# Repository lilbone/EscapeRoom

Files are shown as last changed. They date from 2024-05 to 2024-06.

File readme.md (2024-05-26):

# EscapeRoom Readme

## Beschreibung

Dieses Projekt besteht aus einem Escape Room, der auf einer Website dargestellt wird und von einem Raspberry Pi gehostet wird. Der Raspberry Pi fungiert als Webserver mit Apache 2 und betreibt zusätzlich einen MQTT-Server. Ein ESP8266 steuert mehrere Sensoren und Aktoren, darunter LEDs, Taster, einen LDR-Sensor, ein RFID-Chip Lesegerät und einen DHT-22 Sensor.

Die Website simuliert ein Haus mit drei Räumen und einem Flur. Die Spieler müssen verschiedene Rätsel lösen, die durch die Sensoren und Aktoren gesteuert werden, um von einem Raum zum nächsten zu gelangen. Die Kommunikation zwischen den Sensoren/Aktoren und der Website erfolgt über das MQTT-Protokoll.

## Funktionalitäten

*Raum 1:
   *Ein Spiegel, der beschlägt, wenn der DHT-22-Sensor angehaucht wird, um ein Passwort anzuzeigen. Mit diesem Passwort kann man den zweiten Raum öffnen.
*Raum 2:
   *Ein Morsecode-Rätsel, das durch eine leuchtende LED und einen Ton auf der Website angezeigt wird. Der entschlüsselte Code ermöglicht den Zugang zum nächsten Raum.
*Raum 3:
   *Es gibt drei Plattformen, die in der richtigen Reihenfolge betätigt werden müssen, um die Tür zu öffnen.
   *Vor dem 3. Raum muss man am ESP8266 den dritten Taster betätigen, um das Licht einzuschalten.
   *Ein Schrank enthält einen RFID-Chip, der sichtbar wird, wenn der LDR-Sensor beleuchtet wird.
   *Die letzte Tür kann nur mit dem RFID-Chip geöffnet werden, indem man ihn am ESP8266 einliest und danach die Tür öffnet.

## Verwendung

1. Installation: Befolge die Anweisungen in der install.md, um die benötigte Software zu installieren und den Server einzurichten.
2. Starten: Nach der Installation und Konfiguration starte den Apache2- und MQTT-Server.
3. Zugriff: Die Website ist unter der IP-Adresse des Raspberry Pi erreichbar. Öffne einen Webbrowser und gib die IP-Adresse ein, um das Spiel zu starten.

## Einstellungen

Die Website ist nach der Konfiguration des Apache2 servers und der Installation der benötigten Pakete unter `http://<IP-Adresse>` erreichbar.

## Abhängigkeiten

* MQTT-Tool: Mosquitto (MQTT-Broker)
* JavaScript-Bibliothek für MQTT: Paho MQTT JavaScript Client

## Hinweis

Diese Website wurde entwickelt, um auf einem Webserver (z.B. Apache) zu laufen. Stelle sicher, dass die Berechtigungen der Dateien korrekt gesetzt sind und dass die Skripte ausführbar sind. Zudem ist ein ESP8266 mit folgenden Sensoren und Aktoren erforderlich:

* LEDs
* Taster
* LDR-Sensor
* RFID-Chip Lesegerät
* DHT-22 Sensor

---

Falls weitere Fragen auftreten oder Unterstützung benötigt wird, stehe ich zur Verfügung. Viel Spaß mit dem EscapeRoom! 🎬🍿

## Copyright

© 2024 Matthias

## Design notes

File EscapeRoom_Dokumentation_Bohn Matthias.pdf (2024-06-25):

IT22A WPF Projektarbeit

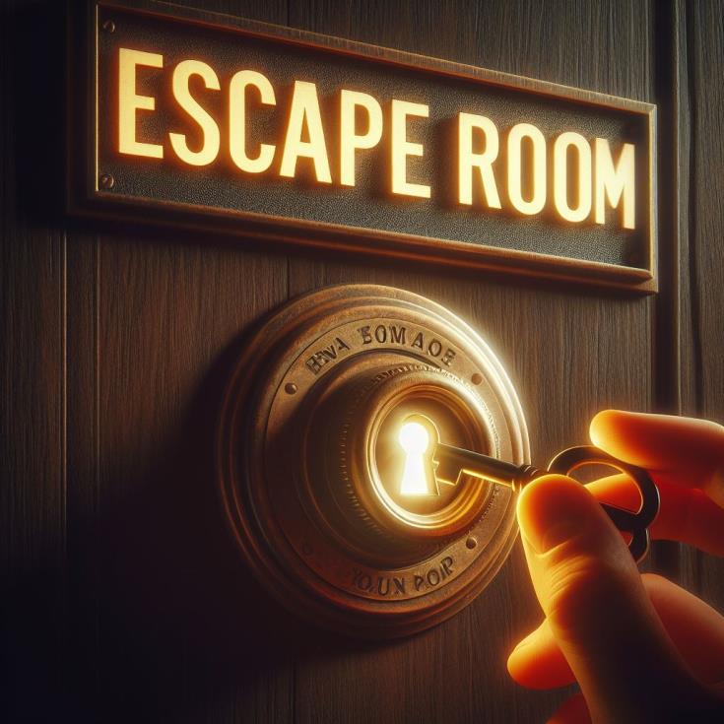
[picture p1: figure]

# ESCAPEROOM WEBSITE

## VERSION 1.1.5

04.06.2024

Vorgestellt von
Bohn Matthias

IT22A WPF Projektarbeit

## Inhaltsverzeichnis

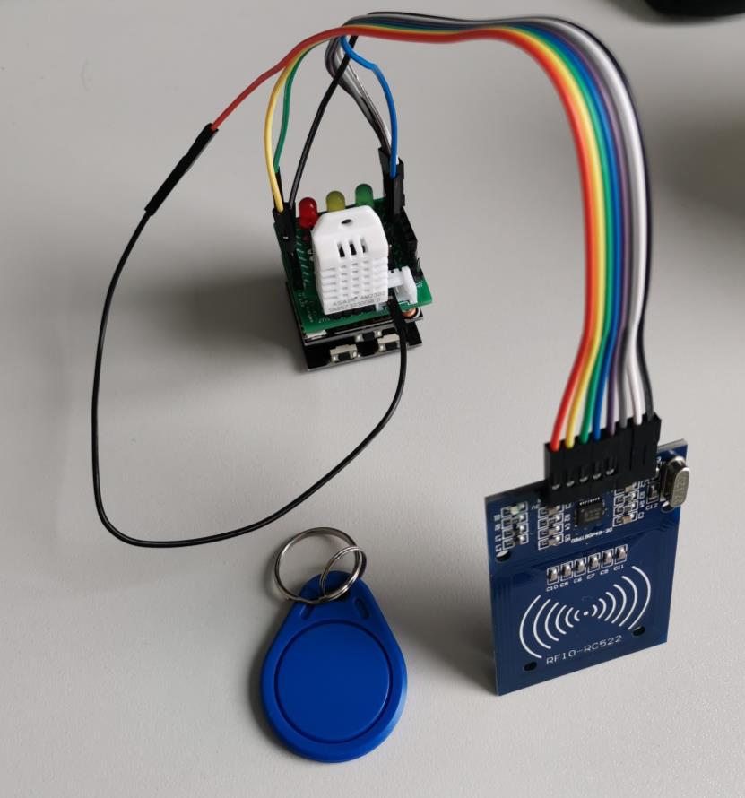
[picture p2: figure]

IT22A WPF Projektarbeit

## Escaperoom website

### Kurzbeschreibung des Produktes

Dieses Projekt besteht aus einem Escape Room, der auf einer Website dargestellt wird und von einem Raspberry Pi gehostet wird. Der Raspberry Pi fungiert als Webserver mit Apache 2 und betreibt zusätzlich einen MQTT-Server. Ein ESP8266 steuert mehrere Sensoren und Aktoren, darunter LEDs, Taster, einen LDR-Sensor, ein RFID-Chip Lesegerät und einen DHT-22 Sensor.

Die Website simuliert ein Haus mit drei Räumen und einem Flur. Der Spieler muss verschiedene Rätsel lösen, die durch die Sensoren und Aktoren gesteuert werden, um von einem Raum zum nächsten zu gelangen und um schlussendlich wieder aus dem Haus zu entkommen. Die Kommunikation zwischen den Sensoren/Aktoren und der Website erfolgt über das MQTT-Protokoll.

### Komponenten und deren Zusammenspiel visualisieren

Realbild:

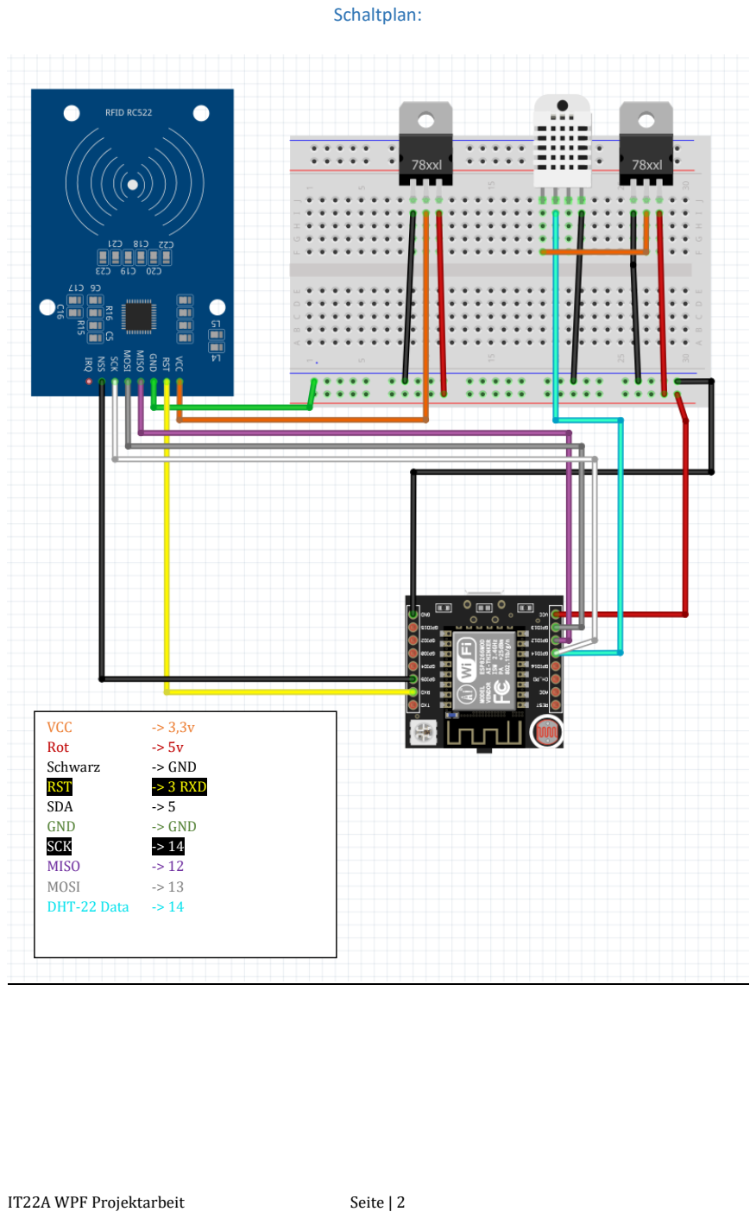
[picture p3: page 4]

IT22A WPF Projektarbeit | Seite | 2

Schaltplan:

VCC | -> 3,3v
Rot | -> 5v
Schwarz | -> GND
RST | -> 3 RXD
SDA | -> 5
GND | -> GND
SCK | -> 14
MISO | -> 12
MOSI | -> 13
DHT-22 Data | -> 14

PAP ESP:

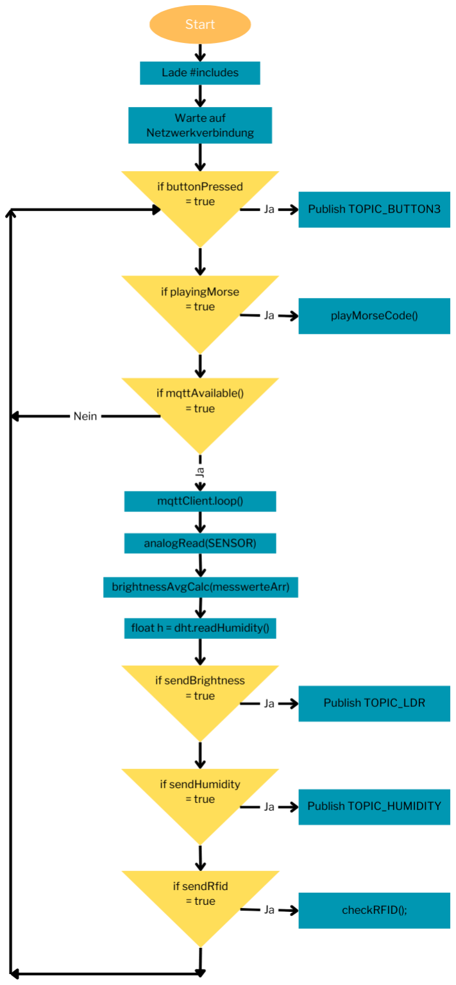
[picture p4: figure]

PAP Javascript / HTML:

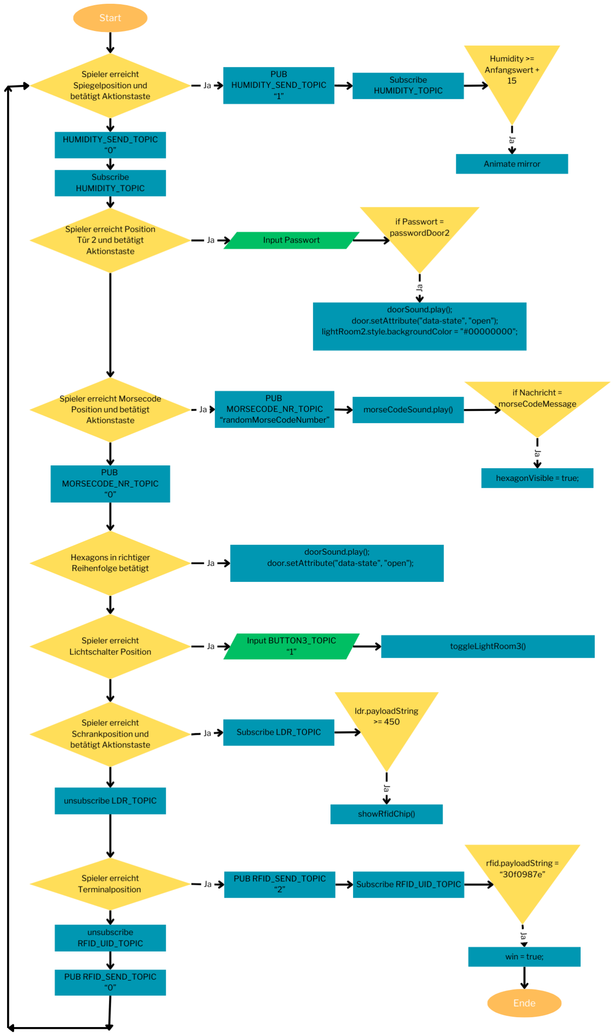
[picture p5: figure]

### Beschreibung der Kommunikationsprotokolle

MQTT-Protokoll:

- Anfrage und Antwort:
- Der ESP8266 sendet Sensordaten (z.B. Luftfeuchtigkeit, Taster Zustand) an den MQTT-Server auf dem Raspberry Pi.
- Die Website abonniert diese Daten und verwendet sie zur Steuerung der Rätsel.
- Nachrichtenaufbau:
- MQTT-Nachrichten bestehen aus einem Topic und einer Payload.
- Topics sind hierarchisch strukturiert, z.B. Sensor/dht22 für den DHT-22 Sensor.
- Payload enthält die eigentlichen Daten, z.B. { "humidity": 60 }.
- Technische Eigenschaften:
- MQTT läuft über TCP/IP.
- Standard-Port für MQTT ist 1883.
- QoS (Quality of Service) Stufen:
- QoS 0: Zustellung nach besten Möglichkeiten
- QoS 1: Mindestens einmalige Zustellung
- QoS 2: Genau einmalige Zustellung

http-Protokoll:

- Anfrage und Antwort:
- Der Browser des Benutzers sendet eine http-Anfrage an den Webserver (Apache 2) auf dem Raspberry Pi.
- Der Webserver antwortet mit den HTML-, CSS-, und JavaScript-Dateien, die die Website darstellen.
- Nachrichtenaufbau:
- http-Anfragen bestehen aus einem Request-Line (z.B. GET /index.html http/1.1), Header-Feldern und optional einer Nachricht.
- HTTP-Antworten bestehen aus einer Statuszeile (z.B. http/1.1 200 OK), Header-Feldern und dem eigentlichen HTML-Inhalt.
- Technische Eigenschaften:
- http läuft über TCP/IP, normalerweise auf Port 80.
- Verbindungsaufbau:
- Client-Server-Modell, bei dem der Client (Browser) Anfragen stellt und der Server (Raspberry Pi) antwortet.

Tabelle der wichtigsten Protokollparameter:

Protokoll | Port | Transport Layer | Sicherheit
MQTT | 1883 | TCP/IP | Optional
Http | 80 | TCP/IP | Keine

### Installation

Installation von git unter Linux

Führe die folgenden Befehle aus, um git auf einem Linux-System zu installieren:

sudo apt update
sudo apt install git

MQTT auf dem Raspberry Pi installieren

Installiere das MQTT-Paket (Mosquitto) auf dem Raspberry Pi:

sudo apt update
sudo apt install mosquitto mosquitto-clients
Starte den Mosquitto-Dienst und stelle sicher, dass er beim Systemstart aktiviert ist:

sudo systemctl start mosquitto
sudo systemctl enable mosquitto

Apache2-Konfiguration

Installation von Apache2

sudo apt update
sudo apt install apache2
Füge die folgende Konfiguration zur /etc/apache2/sites-available/000-default.conf hinzu, um den Zugriff auf das Verzeichnis der CGI-Skripte zu ermöglichen:

<VirtualHost *:80>

DocumentRoot /home/mqtt/EscapeRoom

<Directory "/home/mqtt/">
AllowOverride None
Options +ExecCGI -MultiViews +SymLinksIfOwnerMatch Require all granted
</Directory>
ProxyPassMatch | "/ws$" ws://127.0.0.1:9001

</VirtualHost>

Nach den Änderungen muss der Apache Server neu gestartet werden:

service apache2 restart

Dateien von Git herunterladen

Lade die Watch-Pulse Dateien in deinen Projekt-Ordner herunter

cd /home/mqtt/
sudo git clone https://github.com/lilbone/EscapeRoom.git Anschließend musst du noch den Benutzer anpassen:

sudo chmod -R +x /home/mqtt/EscapeRoom

Arduino-Bibliotheken installieren

Um den Sketch escapeRoomSketch.ino auf deinem ESP8266 auszuführen, musst du die folgenden Arduino-Bibliotheken installieren:

- DHT Sensor Library von Adafruit:
- Suche in der Bibliotheksverwaltung nach "DHT sensor library" und installiere sie.
- ESP8266WiFi:
- Diese Bibliothek ist normalerweise mit der Installation des ESP8266-Pakets in der Arduino-IDE enthalten.
- PubSubClient:
- Suche in der Bibliotheksverwaltung nach "PubSubClient" und installiere sie.
- MFRC522:
- Suche in der Bibliotheksverwaltung nach "MFRC522" und installiere sie.
- Streaming:
- Suche in der Bibliotheksverwaltung nach "Streaming" und installiere sie.

ESP8266 vorbereiten

- Taster / LED / Senor-Erweiterung aufstecken
- DHT-22 mit Sensor-Schnittstelle verbinden
- RFID Chip-Reader wie folgt verbinden:
- | Orange 3,3v | -> 3,3v
- | Gelb RST | -> 3 RXD
- | Schwarz SDA | -> 5
- | Grün GND | -> GND
- | Weiß SCK | -> 14
- | Lila MISO | -> 12
- | Grau MOSI | -> 13

### Beschreibung eines besonderen Teils der Umsetzung

RFID-Chip-Reader und Verwendung der Sensoren zur Lösung von Rätseln:

Ein herausragendes Merkmal dieses Projekts ist die Implementierung des RFID-Chip-Readers. Der RFID-Reader am ESP8266 liest den RFID-Chip und sendet die Daten über MQTT an die Website. Sobald der Chip korrekt erkannt wird, kann der Spieler die letzte Tür im Escape Room öffnen.

Darüber hinaus wurde großer Wert darauf gelegt, die Sensoren und Aktoren nicht nur zur Datenerfassung, sondern als aktive Bestandteile der Rätsel zu nutzen:

DHT-22 Sensor: Erkennt Atemfeuchtigkeit, um ein beschlagenes Spiegelbild und ein verborgenes Passwort anzuzeigen.

LED und Ton: Werden verwendet, um Morsecode zu signalisieren, den die Spieler entschlüsseln müssen.

Taster und LDR-Sensor: Interaktionen mit diesen Komponenten schalten Licht ein oder machen den RFID-Chip sichtbar.

Diese kreative Nutzung der Komponenten sorgt für ein interaktives und immersives Erlebnis im Escape Room.

### Programm-code ESP

/* ################################################################
Filename | : escapeRoomSketch.ino
Author | : Bohn Matthias
Date | : 26.05.2024
################################################################ */ #include <DHT.h>

#include <ESP8266WiFi.h>

#include <PubSubClient.h>

#include <MFRC522.h>

#include "Streaming.h"

#include "wifi.h"

#include "params.h"

#include "functions.h"

DHT dht(DHT_PIN, DHT_TYPE); // Initialisierung des DHT-Sensors

void setup() {
Serial.begin(9600);
Serial << endl
<< "Start Escape-Room" << endl;

Serial << F("Version: 1.1.5") << endl << F("Build: ") << F(__TIME__) << F(" ") << F(__DATE__) << endl << F(__FILE__) << endl;

pinMode(LED_YELLOW, OUTPUT);
pinMode(TASTER_3, INPUT_PULLUP); attachInterrupt(digitalPinToInterrupt(TASTER_3), handleButtonPress, FALLING);

WiFi.mode(WIFI_STA);
WiFi.begin(ssid, psk);
// wait for AP association
Serial << "Warte auf Verbindung..." << endl;

while (WiFi.status() != WL_CONNECTED) { delay(500);
Serial << ".";
}

Serial << endl
<< "Mit " << ssid << "verbunden" << endl << endl
<< "IP-Addresse: " << WiFi.localIP() << endl << endl;

//DHT Sensor pinMode(DHT_POWER, OUTPUT); // Konfiguriere den DHT-Stromversorgungspin als Ausgang
digitalWrite(DHT_POWER, HIGH); // Schalte die Stromversorgung für den DHT-Sensor ein
dht.begin(); | // Initialisierung des DHT-Sensors

mqttClient.setServer(MQTT_BROKER, PORT);

mqttAvailable();
mqttClient.setCallback(callback);

Serial << "Setup abgeschlossen" << endl; }

void loop() {
int messwerteArr[ANZAHL_MESSWERTE];
int brightnessAvg = 0;
unsigned long currentMillis = millis(); // Aktuelle Zeit abrufen

if (buttonPressed) {
buttonPressed = false;
publishData(TOPIC_BUTTON3, "1");
}

// Wird kontinuierlich aufgerufen und prüft den Morse-Code-Status if (playingMorse) {
playMorseCode();
}

if (currentMillis - previousMqttMillis >= 200) { previousMqttMillis = currentMillis;
if (mqttAvailable()) {

unsigned long start = millis();
do {
mqttClient.loop(); // Verarbeite den Eingangs-Nachrichtenstapel } while (millis() - start < 200);

if (currentMillis - previousMillis >= interval) {
for (int i = 0; i < ANZAHL_MESSWERTE; i++) { // Messwerte erfassen messwerteArr[i] = analogRead(SENSOR);
}

brightnessAvg = brightnessAvgCalc(messwerteArr); // Durchschnittshelligkeit berechnen

h = dht.readHumidity(); // Luftfeuchtigkeit lesen

if (sendBrightness) {

if (abs(brightnessAvg - brightness) > 50) { brightness = brightnessAvg; publishData(TOPIC_LDR, String(brightnessAvg)); }
}

if (sendHumidity) {
Serial << h << ", " << humidity << endl;
if (abs(round(h) - humidity) > 2) {
humidity = round(h);
publishData(TOPIC_HUMIDITY, String(humidity)); }
}
}

if (sendRfid) {
SPI.begin(); | // SPI-Bus initialisieren
mfrc522.PCD_Init(); // MFRC522 initialisieren

checkRFID();
}
}
}
}

/* ################################################################
Filename | : functions.h
Author | : Bohn Matthias
Date | : 26.05.2024
################################################################ */ #include "WString.h"

#ifndef FUNCTIONS_H

#define FUNCTIONS_H

#include "params.h"

// Interrupt Service Routine (ISR) für das Drücken des Buttons void IRAM_ATTR handleButtonPress() {
buttonPressed = true;
}

// Funktion zum Finden des Index des maximalen Werts im Array
int findMaxIdx(const int messwerteArr[]) {
int maxValue = messwerteArr[0]; | // Initialisierung des
maximalen Werts mit dem ersten Wert im Array

int idx = 0; | // Index des maximalen Werts
initialisieren
for (int i = 1; i < ANZAHL_MESSWERTE; i++) { // Schleife durch alle Messwerte
if (messwerteArr[i] > maxValue) { | // Überprüfen, ob der aktuelle
Wert größer als der bisherige maximale Wert ist
maxValue = messwerteArr[i]; | // Aktualisierung des
maximalen Werts
idx = i; | // Aktualisierung des Index
des maximalen Werts
}
}
return idx; // Rückgabe des Index des maximalen Werts
}

// Funktion zum Finden des Index des minimalen Werts im Array
int findMinIdx(const int messwerteArr[]) {
int minValue = messwerteArr[0]; | // Initialisierung des
minimalen Werts mit dem ersten Wert im Array
int idx = 0; | // Index des minimalen Werts
initialisieren
for (int i = 1; i < ANZAHL_MESSWERTE; i++) { // Schleife durch alle Messwerte
if (messwerteArr[i] < minValue) { | // Überprüfen, ob der aktuelle
Wert kleiner als der bisherige minimale Wert ist
minValue = messwerteArr[i]; | // Aktualisierung des
minimalen Werts
idx = i; | // Aktualisierung des Index
des minimalen Werts
}
}
return idx; // Rückgabe des Index des minimalen Werts
}

// Funktion zur Berechnung des Durchschnitts der Helligkeitswerte
int brightnessAvgCalc(const int messwerteArr[]) {
int AVG = 0; | // Durchschnittsvariable
initialisieren
const int idx_max = findMaxIdx(messwerteArr); // Index des maximalen Werts finden
const int idx_min = findMinIdx(messwerteArr); // Index des minimalen Werts finden

for (int i = 0; i < ANZAHL_MESSWERTE; i++) { // Schleife durch alle Messwerte
if (i != idx_max && i != idx_min) | // Überprüfen, ob der Index
nicht dem Index des maximalen oder minimalen Werts entspricht
{
AVG += messwerteArr[i]; // Wert zum Durchschnitt hinzufügen
}

}
return AVG / (ANZAHL_MESSWERTE - 2); // Durchschnitt berechnen und zurückgeben
}

// Funktion zum Veröffentlichen von Daten über MQTT
void publishData(String topic, String payload) { mqttClient.publish(topic.c_str(), payload.c_str());
Serial << "PUBLISH: Topic = " << topic << " Payload = " << payload << endl; }

// Funktion zur Überprüfung des RFID-Tags
void checkRFID() {
if (mfrc522.PICC_IsNewCardPresent()) { // Überprüfen, ob eine neue Karte vorhanden ist
if (mfrc522.PICC_ReadCardSerial()) { // Überprüfen, ob die Kartendaten gelesen werden können
Serial << "Card UID: ";
for (byte i = 0; i < mfrc522.uid.size; i++) { // Schleife durch die UID-Bytes
if (mfrc522.uid.uidByte[i] < 0x10) {
Serial << " 0";
} else {
Serial << " ";
}
Serial << _HEX(mfrc522.uid.uidByte[i]); // Ausgabe der UID-Bytes in Hexadezimalformat
}
Serial << endl;
// Hier könntest du die UID auch an MQTT senden
String uidString = "";
for (byte i = 0; i < mfrc522.uid.size; i++) { // Erstellen des UID-Strings
uidString += String(mfrc522.uid.uidByte[i] < 0x10 ? "0" : "") + String(mfrc522.uid.uidByte[i], HEX);
}
publishData("esp/rfid/uid", uidString); // UID über MQTT senden sendRfid = false;
mfrc522.PICC_HaltA(); // Stop reading
} else {
Serial << "Error reading card." << endl; }
} else {
Serial << "No card present." << endl;
}
}

// Funktion zum Abspielen des Morse-Codes
void playMorseCode() {
unsigned long currentMorseCodeMillis = millis();

static bool isSymbolSpace = false;

if (playingMorse && currentMorseCodeMillis - previousMillisMorseCode >= waittime) {
previousMillisMorseCode = currentMorseCodeMillis;
char symbol = morseBuffer[morseIndex];

if(prev_sym == '.' || prev_sym == '-'){
digitalWrite(LED_YELLOW, LOW); // LED ausschalten nach einem Symbol publishData(TOPIC_LAMP_STATUS, "0");
waittime = WAIT_TIME;
prev_sym = ' ';
} else if (symbol == '.') {
digitalWrite(LED_YELLOW, HIGH); // LED für Punkt-Symbol einschalten publishData(TOPIC_LAMP_STATUS, "1");
prev_sym = symbol;
waittime = DOT_TIME;
morseIndex++;
} else if (symbol == '-') {
digitalWrite(LED_YELLOW, HIGH); // LED für Strich-Symbol einschalten publishData(TOPIC_LAMP_STATUS, "1");
waittime = HYPHEN_TIME;
prev_sym = symbol;
morseIndex++;
} else if (symbol == ' ') {
digitalWrite(LED_YELLOW, LOW); // LED ausschalten für Leerzeichen publishData(TOPIC_LAMP_STATUS, "0");
waittime = SPACE_TIME;
prev_sym = ' ';
morseIndex++;
} else {
digitalWrite(LED_YELLOW, LOW); // LED ausschalten bei unbekanntem Symbol
playingMorse = false;
publishData(TOPIC_LAMP_STATUS, "0");
morseIndex = 0; // Reset Morse index
}
if (morseIndex >= strlen(morseBuffer)) {
morseIndex = 0; // Wiederholen des Morse-Codes
isSymbolSpace = false; // Startet mit Buchstabenpause beim Wiederholen }
}
}

// Callback-Funktion für eingehende MQTT-Nachrichten
void callback(char* c_topic, byte* payload, unsigned int length) { // Konvertiere Payload in String
String msg, topic;
for (byte i = 0; i < length; i++) {
msg += char(payload[i]);

}
topic = String(c_topic);
Serial << "CALLBACK: Topic = " << topic << " Payload = " << msg << endl;

// Verarbeite empfangene Topics
if (topic == TOPIC_LAMP) {
if (msg == "1") {
digitalWrite(LED_YELLOW, HIGH); publishData(TOPIC_LAMP_STATUS, "1"); }
if (msg == "0") {
digitalWrite(LED_YELLOW, LOW); publishData(TOPIC_LAMP_STATUS, "0"); }
}

if (topic == TOPIC_SEND_HUMIDITY) {
Serial << "send humidity " << msg << endl;
if (msg == "1") {
sendHumidity = true;
publishData(TOPIC_HUMIDITY, String(humidity)); }
if (msg == "0") {
sendHumidity = false;
}
}

if (topic == TOPIC_SEND_LDR) {
Serial << "send brightness " << msg << endl; if (msg == "1") {
sendBrightness = true;
publishData(TOPIC_LDR, String(brightness)); }
if (msg == "0") {
sendBrightness = false;
}
}

if (topic == MORSECODE_NR_TOPIC) {
if (msg == "1") {
strncpy(morseBuffer, SOS, sizeof(morseBuffer) - 1); playingMorse = true;
} else if(msg == "2"){
strncpy(morseBuffer, SEK, sizeof(morseBuffer) - 1); playingMorse = true;
} else if(msg == "3"){
strncpy(morseBuffer, NSA, sizeof(morseBuffer) - 1); playingMorse = true;
} else {
playingMorse = false;

morseIndex = 0;
digitalWrite(LED_YELLOW, LOW); publishData(TOPIC_LAMP_STATUS, "0"); }
}

if (topic == RFID_SEND_TOPIC) { if (msg == "2") {
sendRfid = true;
} else {
sendRfid = false;
}
}
}

// Funktion zur Überprüfung der MQTT-Verfügbarkeit und Verbindung boolean mqttAvailable() {
while (!mqttClient.connected()) { // Überprüfen, ob der MQTT-Client verbunden ist
Serial << "connecting to MQTT-Broker: ";
Serial << MQTT_BROKER << endl;
mqttClient.connect("ESP-Client_xyz"); // Verbindung zum MQTT-Broker herstellen
mqttClient.subscribe(TOPIC_LAMP); // Abonnieren der benötigten Topics mqttClient.subscribe(TOPIC_SEND_HUMIDITY); mqttClient.subscribe(TOPIC_SEND_LDR); mqttClient.subscribe(MORSECODE_NR_TOPIC); mqttClient.subscribe(RFID_SEND_TOPIC);
}
return mqttClient.connected(); // Rückgabe des Verbindungsstatus }

#endif

/* ################################################################
Filename | : params.h
Author | : Bohn Matthias
Date | : 26.05.2024
################################################################ */ #ifndef PARAMS_H

#define PARAMS_H

// MQTT-Parameter
const char* MQTT_BROKER = "192.168.43.133"; const uint16_t PORT = 1883;

WiFiClient espClient;
PubSubClient mqttClient(espClient);

// MQTT-Themen
#define TOPIC_LAMP "esp/lighting/led_yellow"

#define TOPIC_LAMP_STATUS "esp/lighting/led_yellow_status" #define TOPIC_LDR "esp/brightness"

#define TOPIC_SEND_LDR "esp/brightness/send"

#define TOPIC_HUMIDITY "esp/humidity"

#define TOPIC_SEND_HUMIDITY "esp/humidity/send" #define MORSECODE_NR_TOPIC "morsecode/nr" #define TOPIC_TEMPERATURE "esp/temperature" #define TOPIC_BUTTON3 "esp/btn3"

#define RFID_SEND_TOPIC "esp/rfid/send"

// Variablen für RFID
#define RST_PIN D2 // RST-PIN für RC522

#define SS_PIN D1 // SDA-PIN für RC522

volatile bool sendRfid = false;
MFRC522 mfrc522(SS_PIN, RST_PIN); // Erstellen einer MFRC522-Instanz /*
Orange 3,3v | -> 3,3v
Gelb RST | -> 3 RXD
Schwarz SDA | -> 5
Grün GND | -> GND
Weiß SCK | -> 14
Lila MISO | -> 12
Grau MOSI | -> 13
*/

#define TASTER_3 2

volatile bool buttonPressed = false;

//Variablen für DHT22
#define DHT_TYPE DHT22 // Typ des DHT-Sensors

#define DHT_PIN 14 | // Pin, an dem der DHT-Sensor angeschlossen ist

#define DHT_POWER 4 | // Pin zur Stromversorgung des DHT-Sensors

float h;

#define LED_YELLOW 13

// Variablen für LDR
const int SENSOR = 0; | // Analog-Pin, an dem der LDR (Light
Dependent Resistor) angeschlossen ist
const int ANZAHL_MESSWERTE = 25; // Anzahl der Messwerte zur Durchschnittsbildung
const int HYSTERESE = 10; | // Hysterese für den LDR-Wert
bool leaveHyst = true; | // Variable zur Überwachung der Hysterese
volatile bool sendBrightness = false;

// Globale Variablen
volatile bool sendHumidity = false; int brightness = 0;
int humidity = 0;

unsigned long previousMillis = 0; unsigned long previousMqttMillis = 0; const long interval = 200;
unsigned long previousMillisMorseCode = 0;

// MorseCode Variablen
#define DOT_TIME 50

#define HYPHEN_TIME 1000

#define SPACE_TIME 500

#define WAIT_TIME 50

#define SOS " ... --- ... | "

#define SEK " ... . -.- | "

#define NSA " -. ... .- | "

int morseIndex = 0;
bool isLetterSpace = false; volatile bool playingMorse = false; int waittime = 0;
char prev_sym = ' ';
char morseBuffer[50];

#endif

/* ################################################################
Filename | : wifi.h
Author | : Bohn Matthias
Date | : 26.05.2024
################################################################ */ #include <ESP8266WiFi.h>

const char* ssid = "MrRobot"; | // WIFI SSID for station mode
const char* psk = "Pa55wortBohn"; // WIFI PSK

const char* ap_ssid = "EscapeRoomWifi"; // WIFI SSID for AP mode const char* ap_psk = "EscapeRoomWifi"; // WIFI PSK

### Programm-code HTML

<!DOCTYPE html>
<html lang="de">

<head>
<meta charset="UTF-8" />
<meta name="viewport" content="width=device-width, initial-scale=1.0" /> <title>Escape Room</title>
<link rel="stylesheet" href="/css/main.css" />
<link rel="stylesheet" href="/css/room1.css" />
<link rel="stylesheet" href="/css/room2.css" />
<link rel="stylesheet" href="/css/room3.css" />
<link rel="shortcut icon" href="#" type="image/x-icon" /> </head>

<body>
<div id="escaperoom">
<div class="jumbotron"></div>

<div class="door door-master" data-state="close"></div> <div id="exit">Exit</div>

<div id="mirror">
<div id="player-background"></div> <p>PW2<br /><span id="pw-door-2"></span></p> </div>

<div id="room1" class="room small-room">
<div class="door door-1" data-state="open"></div> <div id="mirrorLine"></div>
</div>
<div id="pc-table">
<div class="pc"></div>
</div>
<div id="pc-chair"></div>
<div id="mirror-puzzle-help"></div> <div id="morse-code"></div>
<div id="rommNr1"><p>1</p></div>

<div id="room2" class="room small-room">
<div class="door door-2" data-state="close"></div> </div>
<div id="morse-code-device"></div>
<div id="lightRoom2" class="light small-room"></div> <div id="lightSwitchLabel"></div>
<div id="rommNr2"><p>2</p></div>
<div id="pc-table2">
<div id="printer"></div>

<div id="notes"></div>
<div id="morseCode-puzzle-help"></div> </div>

<div id="room3" class="room big-room">
<div class="door door-3" data-state="close"></div> </div>
<div id="lightRoom3" class="light"></div>
<div id="lightSwitch"></div>
<div id="table-dining"></div>
<div id="schrank"></div>
<div id="wardrobe-open">
<div id="wardrobe-light"></div> <div id="rfid-chip"></div> </div>
<div id="reader"></div>
<div id="alarmLamp"></div>
<div id="rommNr3"><p>3</p></div> <div id="wardrobe-puzzle-help"></div> <div id="candle"></div>

<div id="hexagon1"></div>
<div id="hexagon2"></div>
<div id="hexagon3"></div>

<div id="player"></div>
</div>

<div id="control">
<div id="time">
<h2>Time: 00:00</h2>
</div>
<div id="control-box">
<h2>Steuerung</h2>

<p class="control-text">
<img src="images/control/arrow-keys-left.png" width="30" alt="" /> Links
</p>

<p class="control-text">
<img src="images/control/arrow-keys-right.png" width="30" alt="" /> Rechts
</p>

<p class="control-text">
<img src="images/control/arrow-keys-up.png" width="30" alt="" /> Oben
</p>

<p class="control-text">
<img src="images/control/arrow-keys-down.png" width="30" alt="" /> Unten
</p>

<hr />

<p class="control-text">
<img src="images/control/space_bar.png" height="30" alt="" /> Aktion
</p>

<p class="control-text">
<img src="images/control/mouse.png" height="30" alt="" />Aufnehmen<br>Rucksack vergrößern </p>

<p class="control-text"></p> </div>

<div id="items">
<hr />
<h2>Rucksack</h2>
<div id="morse-code-bag">
<div class="morse-code-image"></div> </div>
<div id="lightSwitchLabel-bag">
<div class="lightSwitchLabel-image"></div> </div>
<div id="rfid-chip-bag">
</div>
</div>
</div>
<script src="js/mqttws31.js"></script> <script src="js/mqtt.js" defer></script>

<script src="js/main.js" defer></script> <script src="js/room1.js" defer></script> <script src="js/room2.js" defer></script> <script src="js/room3.js" defer></script> <script src="js/escaperoom_1.js" defer></script> </body>

</html>

### Programm-code CSS

/* ################################################################
Filename | : main.css
Author | : Bohn Matthias
Date | : 26.05.2024
################################################################ */ * {

margin: 0;
padding: 0;
box-sizing: border-box;
font-family: "Segoe UI", Tahoma, Geneva, Verdana, sans-serif; }
body {
display: flex;
justify-content: center;
align-items: center;
height: 100vh;
background-color: #f0f0f0; }
#escaperoom {

width: 600px;
height: 600px;
background-color: #cbd2d6;
background-image: url("../images/general/wood-floor-hallway.jpg"); background-size: 150px 150px;
position: relative;
border: 8px solid #000;
display: flex;
justify-content: center;
align-items: center;
}

.jumbotron {
z-index: 10;
position: absolute;
top: 150px;
max-width: 450px;
padding: 10px;
background: steelblue;
border-radius: 8px;
box-shadow: snow 0px 0px 26px 5px; display: none;
gap: 8px;
flex-direction: column;
align-items: center;
justify-content: center;
}

.room {

background-color: #666;
background-image: url("../images/general/wood-floor.jpg"); background-size: 400px 400px;
position: absolute;
border: 8px solid #000;
}
.small-room {
width: 252px;
height: 252px;
}
.big-room {
width: 252px;
height: 600px;
}
#room1 {

top: -8px;
left: -8px;
}
#room2 {

bottom: -8px;
left: -8px;
}
#room3 {

top: -8px;
right: -8px;
}
#player {

width: 35px; /* Gesamtbreite des Spieler-Elements einschließlich des zusätzlichen Bildes */
z-index: 3;
height: 35px;
background-image: url("../images/player/player.png"); /* Hintergrundbild des Spielers */
background-size: 35px 35px; /* Größe des Hintergrundbildes für den Spieler */
background-position: left center; /* Position des Spieler-Bildes */ position: absolute;
top: 0px; /* Anpassen, um die gewünschte vertikale Positionierung zu erreichen */
left: 280px; /* Anpassen, um die gewünschte horizontale Positionierung zu erreichen */
}

#player::after {

content: ""; /* Fügt ein Pseudoelement hinzu */ z-index: 2;
display: none;
width: 10px;
height: 20px; /* Höhe des zusätzlichen Bildes */

background-image: url("../images/player/exclamation-mark.png"); /* Hintergrundbild des zusätzlichen Bildes */
background-size: cover; /* Größe des Hintergrundbildes für das zusätzliche Bild */
position: absolute;
top: -10px; /* Anpassen, um die gewünschte vertikale Positionierung zu erreichen */
left: -10px; /* Anpassen, um das zusätzliche Bild neben dem Spieler anzuzeigen */
animation: wobble 0.3s infinite alternate; /* Animation hinzufügen */
}
#player.show-after::after {

display: block; /* Zusätzliches Bild anzeigen, wenn die Klasse 'show-after' vorhanden ist */
}

@keyframes wobble {
from {
transform: rotate(-5deg);
}
to {
transform: rotate(5deg);
}
}

#hexagon1 {

width: 35px; /* Gesamtbreite des Spieler-Elements einschließlich des zusätzlichen Bildes */
height: 35px;
display: none;
background-image: url("../images/general/hexagon-gray.png"); /* Hintergrundbild des Spielers */
background-size: 35px 35px; /* Größe des Hintergrundbildes für den Spieler */
background-position: left center; /* Position des Spieler-Bildes */ position: absolute;
top: 540px;
left: 290px;
}
#hexagon2 {

width: 35px; /* Gesamtbreite des Spieler-Elements einschließlich des zusätzlichen Bildes */
height: 35px;
display: none;
background-image: url("../images/general/hexagon-gray.png"); /* Hintergrundbild des Spielers */
background-size: 35px 35px; /* Größe des Hintergrundbildes für den Spieler */
background-position: left center; /* Position des Spieler-Bildes */ position: absolute;

top: 180px;
left: 20px;
}
#hexagon3 {

width: 35px; /* Gesamtbreite des Spieler-Elements einschließlich des zusätzlichen Bildes */
height: 35px;
display: none;
background-image: url("../images/general/hexagon-gray.png"); /* Hintergrundbild des Spielers */
background-size: 35px 35px; /* Größe des Hintergrundbildes für den Spieler */
background-position: left center; /* Position des Spieler-Bildes */ position: absolute;
top: 530px;
left: 20px;
}

.light {
position: absolute;
background-color: #000000f3; z-index: 3;
}

.door {
position: absolute;
background-color: #b12121; border-radius: 4px;
transition: background-color 1.3s; z-index: 5;
}
.door-1 {
bottom: calc(50% - 35px);
right: -9px;
width: 10px;
height: 70px;
}
.door-2 {
top: -9px;
left: calc(50% - 35px);
width: 70px;
height: 10px;
}
.door-3 {
bottom: calc(50% - 35px);
left: -9px;
width: 10px;
height: 70px;
}
.door-master {

left: calc(50% - 35px);
top: -9px;
width: 70px;
height: 10px;
}
div[data-state="open"] {
background-color: #568f44; /* Hier die gewünschte Hintergrundfarbe einfügen */
}

#exit {

position: absolute;
left: calc(50% - 17px);
top: -32px;
font-size: 18px;
font-weight: 700;
font-family: cursive;
}

#time{

margin-bottom: 10px;
color: #4682b4;
}

#control {

margin-left: 30px;
}

#control-box {

display: flex;
flex-direction: column;
gap: 8px;

.control-text {
display: flex;
align-items: center;

img{
margin-right: 10px;
}
}
}

#items {

margin-top: 20px;
display: flex;
gap: 8px;
flex-direction: column;
align-items: center;
}

#morse-code-bag {

position: relative;
background-image: url("../images/room1/morse-codes.png"); background-size: cover;
width: 40px;
height: 60px;
display: none;
}

.morse-code-image {
position: absolute; /* Positionierung relativ zum Elternelement */ top: 50%;
left: 50%;
transform: translate(-500px, -400px);
background-image: url("../images/room1/morse-codes.png"); background-size: cover;
width: 300px;
height: 450px;
z-index: 10;
opacity: 0; /* Das Bild ist standardmäßig unsichtbar */
transition: opacity 0.3s; /* Übergangseffekt für die Sichtbarkeit */ pointer-events: none;
}

#morse-code-bag:hover .morse-code-image {

opacity: 1; /* Bild wird sichtbar, wenn über das Elternelement geschwebt wird */
}

#lightSwitchLabel-bag {

position: relative;
background-image: url("../images/room2/light-switch-horizontal.png"); background-size: cover;
width: 100px;
height: 29px;
display: none;
}

.lightSwitchLabel-image {
position: absolute; /* Positionierung relativ zum Elternelement */ top: 50%;
left: 50%;
transform: translate(-500px, -200px);
background-image: url("../images/room2/light-switch-horizontal.png"); background-size: cover;
width: 200px;
height: 58px;
z-index: 10;
opacity: 0; /* Das Bild ist standardmäßig unsichtbar */

transition: opacity 0.3s; /* Übergangseffekt für die Sichtbarkeit */ pointer-events: none;
}

#lightSwitchLabel-bag:hover .lightSwitchLabel-image {

opacity: 1; /* Bild wird sichtbar, wenn über das Elternelement geschwebt wird */
}

#rfid-chip-bag {

position: relative;
background-image: url("../images/room3/rfid-chip.png"); background-size: cover;
width: 58px;
height: 60px;
display: none;
}

/* ################################################################
Filename | : room1.css
Author | : Bohn Matthias
Date | : 26.05.2024
################################################################ */ @keyframes backgroundFadeIn {

0% {
background: linear-gradient(to bottom, #b3b1b1, #837e7e);
}
100% {
background: linear-gradient(to bottom, #e6e5e5, #919191); }
}

@keyframes textFadeIn {
0% {
color: rgba(240, 248, 255, 0);
}
100% {
color: rgba(255, 255, 255, 0.45); }
}

@keyframes playerOpacity { 0% {
opacity: 1;
}
100% {

opacity: 0.3;
}
}

#mirror {

z-index: 10;
position: absolute;
display: none;
top: 50px;
left: 45px;
height: 200px;
width: 150px;
background: linear-gradient(to bottom, #b3b1b1, #837e7e); border: 6px solid #457eb6;
border-radius: 2px;
overflow: hidden;
}
.animateMirror {
animation: backgroundFadeIn 4s forwards; }

#mirror p {

font-weight: 800;
text-align: center;
margin-top: 30px;
font-family: cursive;
font-size: 20px;
color: rgba(240, 248, 255, 0);
}
.animate-mirror-p {
animation: textFadeIn 4s forwards; }

#player-background {

background-image: url(../images/player/player.png); background-size: 100px 100px;
background-position: center;
background-repeat: no-repeat;
width: 100%;
height: 100%;
filter: blur(1px);
opacity: 1;
position: absolute;
top: 85px;
}
.animate-layer-background { animation: playerOpacity 3s forwards; }

#mirrorLine {

position: absolute;
background-color: #457eb6; top: 0;
left: 160px;
width: 55px;
height: 6px;
}

#pc-table {

position: absolute;
z-index: 1;
background-image: url("../images/room1/pc-table.png"); background-repeat: no-repeat;
background-size: cover;
top: 0;
left: 5px;
width: 88px;
height: 35px;
}

#pc-table .pc {

background-image: url("../images/room1/pc.png"); background-size: cover;
background-repeat: no-repeat;
position: relative;
left: 12px;
width: 66px;
height: 32px;
}

#pc-chair {

z-index: 0;
position: absolute;
background-image: url("../images/room1/pc-chair.png"); background-repeat: no-repeat;
background-size: cover;
top: 20px;
left: 30px;
width: 36px;
height: 34px;
}

#mirror-puzzle-help {

z-index: 3;
position: absolute;
background-image: url("../images/room1/email.png"); background-repeat: no-repeat;
background-size: cover;
display: none;
top: 3px;

left: 60px;
width: 18px;
height: 18px;
border-radius: 50%;
animation: wobble 0.3s infinite alternate; box-shadow: -1px 1px 5px 1px;
}

#morse-code {

position: absolute;
background-image: url("../images/room1/morse-codes.png"); background-repeat: no-repeat;
background-size: cover;
top: 173px;
left: 178px;
width: 31px;
height: 46px;
}

#rommNr1 {

position: absolute;
font-weight: bold;
top: 59px;
left: 235px;
color: #faebd7;
}

/* ################################################################
Filename | : room2.css
Author | : Bohn Matthias
Date | : 26.05.2024
################################################################ */ #morse-code-device {

position: absolute;
background-image: url("../images/room2/morse-code-device.png"); background-repeat: no-repeat;
background-size: cover;
top: 400px;
left: 200px;
width: 36px;
height: 57px;
}

#lightRoom2 {

bottom: -8px;
left: -8px;
/* background-color: transparent; */

}

#lightSwitchLabel {

position: absolute;
background-image: url("../images/room2/light-switch.png"); background-repeat: no-repeat;
background-size: cover;
top: 390px;
left: 10px;
width: 13px;
height: 50px;
}

#pc-table2 {

position: absolute;
background-image: url("../images/room1/pc-table.png"); background-repeat: no-repeat;
background-size: cover;
top: 549px;
left: 100px;
width: 88px;
height: 35px;

#notes {

background-image: url("../images/room2/notes.png"); width: 23px;
height: 24px;
background-repeat: no-repeat;
background-size: cover;
position: relative;
top: -18px;
left: 8px;
}

#printer {

background-image: url("../images/room2/printer.png"); width: 40px;
height: 25px;
background-repeat: no-repeat;
background-size: cover;
position: relative;
top: 8px;
left: 43px;
}

#morseCode-puzzle-help {

position: relative;
background-image: url("../images/room2/prints.png"); background-repeat: no-repeat;
background-size: cover;

display: block;
top: -45px;
left: 54px;
width: 17px;
height: 20px;
animation: wobble 0.3s infinite alternate; box-shadow: -1px 1px 5px 1px;
}
}

#rommNr2 {

position: absolute;
font-weight: bold;
transform: rotateZ(-90deg); z-index: 3;
top: 333px;
left: 161px;
color: #faebd7;
}

/* ################################################################
Filename | : room3.css
Author | : Bohn Matthias
Date | : 26.05.2024
################################################################ */ #table-dining {

position: absolute;
background-image: url("../images/room3/table-dining.png"); background-repeat: no-repeat;
background-size: cover;
top: 370px;
left: 430px;
width: 106px;
height: 170px;
}

#schrank {

position: absolute;
background-image: url("../images/room3/Schrank.png"); background-repeat: no-repeat;
background-size: cover;
top: 0px;
left: 430px;
width: 109px;
height: 33px;
}

#wardrobe-open {

position: absolute;
z-index: 11;
background-image: url("../images/room3/Schrank-open.png"); background-repeat: no-repeat;
background-size: cover;
display: none;
top: -15px;
left: 360px;
width: 220px;
height: 220px;
transition: all 1.5s;

#wardrobe-light {

background-color: black;
width: 126px;
height: 152px;
position: relative;
top: 34px;
left: 49px;
transition: all 2s;
}

#rfid-chip {

background-image: url("../images/room3/rfid-chip.png"); background-repeat: no-repeat;
background-size: cover;
border-radius: 8px;
width: 29px;
height: 30px;
position: relative;
top: -50px;
left: 96px;
opacity: 0;
transition: all 1s;
animation: wobble 0.3s infinite alternate; }
#rfid-chip:hover {

background-color: #fafad2;
}
}

#lightRoom3 {

top: 0px;
left: 348px;
z-index: 4;
width: 236px;
height: 584px;
}

#lightSwitch {

position: absolute;
background-color: #ffffff; /*#fdf300*/ top: 340px;
left: 335px;
width: 5px;
height: 15px;
z-index: 1;
}

#alarmLamp {

position: absolute;
background-image: url("../images/room3/revolving-light-red.png"); background-size: cover;
top: 125px;
left: 348px;
width: 25px;
height: 25px;
z-index: 1;
}

#reader {

position: absolute;
background-image: url("../images/room3/reader.png"); background-size: cover;
top: 155px;
left: 348px;
width: 35px;
height: 44px;
}

#rommNr3 {

position: absolute;
font-weight: bold;
top: 232px;
left: 339px;
color: #faebd7;
}

#wardrobe-puzzle-help {

position: absolute;
background-image: url("../images/room3/info.png"); background-repeat: no-repeat;
background-size: cover;
display: none;
top: 390px;
right: 95px;
width: 12px;
height: 25px;

animation: wobble 0.3s infinite alternate; }

#candle {

position: absolute;
background-image: url("../images/room3/candle.png"); background-repeat: no-repeat;
background-size: cover;
top: 446px;
right: 91px;
width: 19px;
height: 21px;
}

### Programm-code Javascript

/* ################################################################
Filename | : main.js
Author | : Bohn Matthias
Date | : 26.05.2024
################################################################ */ // Initialisierung von Variablen

let playerSize = 35; // Größe des Spielers in Pixel
let win = false; // Zustand des Spiels: gewonnen oder nicht

let themeSoundIsPlaying = false; // Zustand der Hintergrundmusik: spielt oder nicht

// Laden und Einstellen der Audiodateien
const stepSound = new Audio('../sounds/step2.mp3'); stepSound.volume = 0.4;
const doorSound = new Audio('../sounds/dooropened.mp3'); doorSound.volume = 0.8;
const hexagonSound = new Audio('../sounds/hexagon.mp3'); hexagonSound.volume = 0.9;
const hexagonOffSound = new Audio('../sounds/hexagon-off.mp3'); hexagonSound.volume = 0.9;
const newNotificationSound = new Audio('../sounds/new-notification.mp3'); newNotificationSound.volume = 0.9;
const lightAmpSound = new Audio('../sounds/light-amp.mp3'); lightAmpSound.volume = 0.7;

// Funktion zum Abspielen des Schrittgeräusches
function playStepSound() {
stepSound.play();
}

// Funktion zum Abspielen der Hintergrundmusik
function playThemeSound() {
const themeSound_1 = new Audio('../sounds/Final Fantasy V - A Presentiment.mp3');
themeSound_1.volume = 0.1;
themeSound_1.loop = true; // Dauerschleife aktivieren

themeSound_1.play(); // Wiedergabe starten
}

// Funktion zum Überprüfen, ob eine Tür geöffnet ist function canMoveThroughDoor(number) {
const door = document.querySelector(`.door-${number}`); return door.dataset.state === "open";
}

// Funktion zur Überprüfung von Kollisionen mit Objekten im Raum
function checkCollisionWithObjects(playerPosition, playerPositionBefore, room) {
// Auswahl der Objekte im aktuellen Raum
let roomObjects;
if (room === 1) {
roomObjects = room1Objects;
} else if (room === 2) {
roomObjects = room2Objects; } else if (room === 3) {
roomObjects = room3Objects;
} else {
roomObjects = []; // Leere Liste, falls kein Raum gefunden wurde }

// Überprüfung jeder Objektposition im aktuellen Raum
for (const object of roomObjects) {
// Berechnung der Objektgrenzen
const objectLeft = object.left;
const objectRight = object.left + object.width; const objectTop = object.top;
const objectBottom = object.top + object.height;

// Überprüfung, ob der Spieler mit dem Objekt kollidiert

if (playerPositionBefore.left >= objectRight && playerPosition.left < objectRight && playerPosition.top + playerSize > objectTop && playerPosition.top < objectBottom ) {
// Spieler kollidiert mit dem Objekt von rechts playerPosition.left = objectRight;
return true;
} else if (playerPositionBefore.left + playerSize <= objectLeft && playerPosition.left + playerSize > objectLeft && playerPosition.top + playerSize > objectTop && playerPosition.top < objectBottom ) {

// Spieler kollidiert mit dem Objekt von links playerPosition.left = objectLeft - playerSize; return true;
} else if (playerPositionBefore.top >= objectBottom && playerPosition.top < objectBottom && playerPosition.left + playerSize > objectLeft && playerPosition.left < objectRight ) {
// Spieler kollidiert mit dem Objekt von unten playerPosition.top = objectBottom;
return true;
} else if (playerPositionBefore.top + playerSize <= objectTop && playerPosition.top + playerSize > objectTop && playerPosition.left + playerSize > objectLeft && playerPosition.left < objectRight ) { // Spieler kollidiert mit dem Objekt von oben playerPosition.top = objectTop - playerSize; return true;
}
}

// Keine Kollision mit Objekten return false;
}

// Funktion zur Überprüfung von Kollisionen mit Gegenständen im Raum function checkCollisionWithItems(playerPosition, playerPositionBefore) { // Auswahl der Gegenstände im aktuellen Raum
let items = itemObjects;
// Überprüfung jeder Gegenstandsposition im aktuellen Raum
for (const item of items) {
// Berechnung der Gegenstandsgrenzen
const itemLeft = item.left;
const itemRight = item.left + item.width; const itemTop = item.top;
const itemBottom = item.top + item.height;

// Überprüfung, ob der Spieler mit dem Gegenstand kollidiert
if ( playerPositionBefore.left >= itemRight && playerPosition.left < itemRight && playerPosition.top + playerSize > itemTop && playerPosition.top < itemBottom ) {
document.getElementById(item.backpackId).style.display = "block"; // Gegenstand in den Rucksack verschieben document.getElementById(item.id).style.display = "none"; // Gegenstand aus dem Raum entfernen
return true;
} else if ( playerPositionBefore.left + playerSize <= itemLeft && playerPosition.left + playerSize > itemLeft && playerPosition.top + playerSize > itemTop && playerPosition.top < itemBottom ) { document.getElementById(item.backpackId).style.display = "block"; // Gegenstand in den Rucksack verschieben document.getElementById(item.id).style.display = "none"; // Gegenstand aus dem Raum entfernen

return true;
} else if ( playerPositionBefore.top >= itemBottom && playerPosition.top < itemBottom && playerPosition.left + playerSize > itemLeft && playerPosition.left < itemRight ) { document.getElementById(item.backpackId).style.display = "block"; // Gegenstand in den Rucksack verschieben document.getElementById(item.id).style.display = "none"; // Gegenstand aus dem Raum entfernen
return true;
} else if ( playerPositionBefore.top + playerSize <= itemTop && playerPosition.top + playerSize > itemTop && playerPosition.left + playerSize > itemLeft && playerPosition.left < itemRight ) { document.getElementById(item.backpackId).style.display = "block"; // Gegenstand in den Rucksack verschieben document.getElementById(item.id).style.display = "none"; // Gegenstand aus dem Raum entfernen
return true;
}
}

// Keine Kollision mit Gegenständen return false;
}

/* ################################################################
Filename | : mqtt.js
Author | : Bohn Matthias
Date | : 26.05.2024
################################################################ */ // Globale Variablen

var client = null; // MQTT-Client
var led_is_on = null; // Status der LED, benötigt für led_toggle()
let firstHumidityPub = true; // Status für die erste Veröffentlichung der Luftfeuchtigkeit

// Konfigurationen
const HOSTNAME = "192.168.43.133";
const PORT = "80";
const PATH = "/ws";
const CLIENTID = "mqtt_js_" + parseInt(Math.random() * 100000, 10);

const LDR_TOPIC = "esp/brightness"; // Thema für den Helligkeitssensor const TOPIC_SEND_LDR = "esp/brightness/send";

const HUMIDITY_TOPIC = "esp/humidity"; // Thema für die Luftfeuchtigkeit const HUMIDITY_SEND_TOPIC = "esp/humidity/send"; // Thema zum Senden der Luftfeuchtigkeit const TEMPERATURE_TOPIC = "esp/temperature"; // Thema für die Temperatur

const RFID_SEND_TOPIC = "esp/rfid/send"; // Thema zum Senden des RFID const RFID_UID_TOPIC = "esp/rfid/uid"; // Thema zum Empfangen der RFID-UID

const TOPIC_LAMP = "esp/lighting/led_yellow"; // Thema für die rote LED const LAMP_STATUS_TOPIC = "esp/lighting/led_yellow_status"; // Thema für den Status der roten LED

const BUTTON3_TOPIC = "esp/btn3"; // Thema für den dritten Button

const MORSECODE_NR_TOPIC = "morsecode/nr"; // Thema für den Morsecode

let humidity = 0; // Variable zur Speicherung der aktuellen Luftfeuchtigkeit let firstHumidity = 0; // Variable zur Speicherung der ersten gemessenen Luftfeuchtigkeit

window.onload = connect(); // Wenn die Webseite vollständig geladen ist, wird connect() aufgerufen

// Hauptfunktion zum Herstellen der Verbindung zum MQTT-Broker
function connect() {
// Client einrichten
client = new Paho.MQTT.Client(HOSTNAME, Number(PORT), PATH, CLIENTID); console.info(
"Verbindung zum Server wird hergestellt: Hostname: ",
HOSTNAME,
". Port: ",
PORT,
". Client ID: ",
CLIENTID
);

// Callback-Handler setzen
client.onConnectionLost = onConnectionLost; // Bei Verbindungsverlust client.onMessageArrived = onMessageArrived; // Bei eintreffenden Nachrichten

// Optionen für die Verbindung setzen
var options = {
onSuccess: onConnect, // Nach erfolgreicher Verbindung wird onConnect aufgerufen
onFailure: onFail, // Bei Fehlschlagen der Verbindung
};

// Client mit den oben festgelegten Optionen verbinden client.connect(options);
console.info("Verbindung wird hergestellt...");
}

// Funktion, die bei erfolgreicher Verbindung zum MQTT-Broker aufgerufen wird function onConnect(context) {
console.log("Client verbunden");

// Optionen für das Abonnieren von Themen options = {
qos: 0,
onSuccess: function (context) { console.log("> SUB-ACK");
},
};
// Relevante Themen abonnieren client.subscribe(LAMP_STATUS_TOPIC, options);

// Nachricht mit Wert 0 senden
message = new Paho.MQTT.Message("0"); message.destinationName = RFID_SEND_TOPIC; message.retained = true;
console.log("< PUB", message.destinationName, "0"); client.send(message);
}

// Funktion, die aufgerufen wird, wenn die Verbindung zum MQTT-Broker fehlschlägt
function onFail(context) {
console.log("Verbindung fehlgeschlagen");
}

// Funktion, die aufgerufen wird, wenn die Verbindung zum MQTT-Broker verloren geht
function onConnectionLost(responseObject) {
if (responseObject.errorCode !== 0) {
console.log("Verbindung verloren: " + responseObject.errorMessage); window.alert("Verbindung verloren: " + responseObject.errorMessage); }
}

// Funktion, die aufgerufen wird, wenn eine MQTT-Nachricht eintrifft function onMessageArrived(message) {
console.log("> PUB", message.destinationName, message.payloadString);

// Aktualisieren der Elemente der Webseite basierend auf dem Thema der Nachricht
if (message.destinationName == LDR_TOPIC) {
if (message.payloadString >= 450) {
showRfidChip(true);
} else {
showRfidChip(false);
}
} else if (message.destinationName == LAMP_STATUS_TOPIC) {

// Status der LED basierend auf der Nachricht aktualisieren if (message.payloadString == "1") { morseCodeSound.play();
led_is_on = true;
} else {
morseCodeSound.pause();
morseCodeSound.currentTime = 0;
led_is_on = false;
}
} else if (message.destinationName == HUMIDITY_TOPIC) { // Erste Veröffentlichung der Luftfeuchtigkeit speichern if (firstHumidityPub) {
firstHumidity = message.payloadString; firstHumidityPub = false;
}
humidity = message.payloadString;
} else if (message.destinationName == BUTTON3_TOPIC) { if (message.payloadString == "1") { toggleLightRoom3(); // Licht im Raum 3 umschalten
}
} else if (message.destinationName == RFID_UID_TOPIC) {
// Aktion ausführen, wenn die richtige RFID-UID empfangen wird if (message.payloadString == "30f0987e") {
win = true;
lightAmpSound.play();
document.getElementById("alarmLamp").style.backgroundImage = "url('../images/room3/revolving-light-green.png')";
}
}
}

// Funktion zum Abonnieren eines Themas function subscribe_topic(topic) { options = {
qos: 0,
onSuccess: function (context) { console.log("> SUB-Ack " + topic); },
};
console.log("> SUB " + topic); client.subscribe(topic, options); }

// Funktion zum Umschalten der LED function led_toggle() {
var payload;
if (led_is_on) {
payload = "0";
led_is_on = false;
} else {

payload = "1";
led_is_on = true;
}

// Nachricht mit dem neuen LED-Status senden message = new Paho.MQTT.Message(payload); message.destinationName = TOPIC_LAMP;
message.retained = true;
console.log("< PUB", message.destinationName, payload); client.send(message);
}

/* ################################################################
Filename | : escaperoom_1.js
Author | : Bohn Matthias
Date | : 26.05.2024
################################################################ */ // Initialisiere die Spielerposition

let playerPosition = {
top: 0,
left: 280,
};

// Variablen zur Verfolgung des aktuellen Zustands let jumbotronVisible = false;
let actualRoom = 0;
let hexagonVisible = false;
let hexagon1Active = false; let hexagon2Active = false; let hexagon3Active = false; let seconds = 0;

// Variablen für die Rätsel
let puzzleSeconds = 0;
let mirrorPuzzle = false;
let mirrorPuzzleFirstHelp = false; let morseCodePuzzle = false;
let morseCodePuzzleFirstHelp = false; let lightSwitch3Puzzle = false;
let lightSwitch3PuzzleFirstHelp = false; let hexagonPuzzle = false;
let hexagonPuzzleFirstHelp = false; let wardrobePuzzle = false;
let wardrobePuzzleFirstHelp = false;

let updateTimeInterval;

// Liste der Gegenstandsobjekte
const itemObjects = [
{ id: 'morse-code', backpackId: 'morse-code-bag', top: 178, left: 183, width: 21, height: 36 },
{ id: 'lightSwitchLabel', backpackId: 'lightSwitchLabel-bag', top: 390, left: 10, width: 13, height: 50 },
];

// Jumbotron-Element
let jumbotronElem = document.querySelector(".jumbotron");

// Willkommensnachricht im Jumbotron anzeigen jumbotronElem.innerHTML = `
<h2>Willkommen</h2>
<p>Du bist in einem alten, verlassenen Herrenhaus gefangen. Um zu entkommen, musst du eine Reihe kniffliger Rätsel lösen. Nutze die versteckten Hinweise und zeige,
dass du scharfsinnig genug bist, um den Weg nach draußen zu finden. Deine Zeit läuft - kannst du das Geheimnis des Hauses lüften und entkommen?</p><p>Tipp: Nutze den ESP und den Computersound um die Rätsel zu lösen.</p>
<p style="display: flex; gap: 10px;"><img src="images/control/space_bar.png" height="20" alt=""><span>Drücke die Space Taste zum Starten</span></p>
`;
jumbotronElem.style.display = "flex"; // Jumbotron sichtbar machen jumbotronVisible = true; // Zustand aktualisieren

// Funktion zur Zeitformatierung
function pad(value) {
return value.toString().padStart(2, '0'); }

// Funktion zur Zeitaktualisierung
function updateTime() {
// Berechne Minuten und Sekunden
const minutes = Math.floor(seconds / 60); const secs = seconds % 60;

// Formatiere die Zeit
const formattedTime = `Time: ${pad(minutes)}:${pad(secs)}`;

// Aktualisiere die Zeitanzeige
document.querySelector("#time h2").textContent = formattedTime;

// Überprüfe die Zeit für die jeweiligen Rätsel und zeige Hilfetexte an const mirrorPuzzleHelpElem = document.getElementById("mirror-puzzle-help");
if (!mirrorPuzzle) {

if (puzzleSeconds == 80 && !mirrorPuzzleFirstHelp) { mirrorPuzzleFirstHelp = true; newNotificationSound.play(); mirrorPuzzleHelpElem.style.display = "block"; }
} else if (!lightSwitch3PuzzleFirstHelp && !mirrorPuzzleFirstHelp) { mirrorPuzzleHelpElem.style.display = "none";
}

const morseCodePuzzleHelpElem = document.getElementById("morseCode-puzzle-help");
if (!morseCodePuzzle && mirrorPuzzle) {
if (puzzleSeconds == 70 && !morseCodePuzzleFirstHelp) { morseCodePuzzleFirstHelp = true; newNotificationSound.play(); morseCodePuzzleHelpElem.style.display = "block"; }
} else {
morseCodePuzzleHelpElem.style.display = "none";
}

const lightSwitch3PuzzleHelpElem = document.getElementById("mirror-puzzle-help");
if (!lightSwitch3Puzzle && mirrorPuzzle && morseCodePuzzle && hexagonPuzzle) {
if (puzzleSeconds == 70 && !lightSwitch3PuzzleFirstHelp) { lightSwitch3PuzzleFirstHelp = true; newNotificationSound.play(); lightSwitch3PuzzleHelpElem.style.display = "block";
}
} else if (!lightSwitch3PuzzleFirstHelp && !mirrorPuzzleFirstHelp) { lightSwitch3PuzzleHelpElem.style.display = "none";
}

const wardrobePuzzleHelpElem = document.getElementById("wardrobe-puzzle-help");
if (!wardrobePuzzle && mirrorPuzzle && morseCodePuzzle && hexagonPuzzle && lightSwitch3Puzzle) {
if (puzzleSeconds == 70 && !wardrobePuzzleFirstHelp) { wardrobePuzzleFirstHelp = true; newNotificationSound.play(); wardrobePuzzleHelpElem.style.display = "block"; }
} else if (!wardrobePuzzleFirstHelp && !mirrorPuzzleFirstHelp) { wardrobePuzzleHelpElem.style.display = "none";
}

// Erhöhe die Sekunden
seconds++;
puzzleSeconds++;

}

// Funktion zum Verstecken des Jumbotrons
function hideJumbotron() {
const jumbotron = document.querySelector(".jumbotron"); if (jumbotron) {
jumbotron.style.display = "none";
jumbotronVisible = false;

// Entferne den Event-Listener, um Mehrfachausführungen zu verhindern document.removeEventListener("keydown", hideJumbotron);
}

// Starten der Hintergrundmusik, falls sie nicht bereits spielt if (!themeSoundIsPlaying) {
playThemeSound();
themeSoundIsPlaying = true;
}

// Starte den Timer und aktualisiere die Zeit jede Sekunde updateTimeInterval = setInterval(updateTime, 1000);

// Rufe die Funktion sofort auf, um den initialen Wert zu setzen updateTime();
}

// Event-Listener hinzufügen, um das Jumbotron zu verstecken document.addEventListener("keydown", hideJumbotron);

// Event-Listener für Tastatureingaben hinzufügen document.addEventListener("keydown", function (event) { const player = document.getElementById("player");

// Vorherige Spielerposition speichern
let playerPositionBefore = {
top: playerPosition.top,
left: playerPosition.left,
};

// Spielerbewegung basierend auf der gedrückten Pfeiltaste switch (event.key) {
case "ArrowUp":
playerPosition.top -= 15;
playStepSound();
break;
case "ArrowDown":
playerPosition.top += 15;
playStepSound();
break;
case "ArrowLeft":

playerPosition.left -= 15; playStepSound();
break;
case "ArrowRight":
playerPosition.left += 15; playStepSound();
break;
}

// Spielerposition begrenzen
if (playerPosition.top < 0) playerPosition.top = 0;
if (playerPosition.top > 550) playerPosition.top = 550; if (playerPosition.left < 0) playerPosition.left = 0;
if (playerPosition.left > 550) playerPosition.left = 550;

// Kollision mit den Wänden und Objekten in den Räumen überprüfen checkMoveRoom1RightWall(playerPositionBefore, playerPosition); checkMoveRoom1BottomWall(playerPositionBefore, playerPosition); checkMoveRoom2RightWall(playerPositionBefore, playerPosition); checkMoveRoom2TopWall(playerPositionBefore, playerPosition); checkMoveRoom3LeftWall(playerPositionBefore, playerPosition); const isColliding = checkCollisionWithObjects(playerPosition, playerPositionBefore, actualRoom);

// Spielerposition aktualisieren, wenn keine Kollision vorliegt player.style.top = playerPosition.top + "px"; player.style.left = playerPosition.left + "px";

// Kollisionen in den Räumen überprüfen checkRoom1MirrorPos(playerPosition, playerPositionBefore);
if ((!mirrorPuzzle && mirrorPuzzleFirstHelp) || (!lightSwitch3Puzzle && lightSwitch3PuzzleFirstHelp)) {
checkRoom1PcPos(playerPosition, playerPositionBefore);
}

checkRoom2DoorPos(playerPosition, playerPositionBefore); checkRoom2MorseCodePos(playerPosition, playerPositionBefore); if (!morseCodePuzzle && morseCodePuzzleFirstHelp) { checkRoom2TablePos(playerPosition, playerPositionBefore); }

checkRoom3LightSwitchPos(playerPosition, playerPositionBefore); checkRoom3WardrobePos(playerPosition, playerPositionBefore); checkRoom3ReaderPos(playerPosition, playerPositionBefore);
if (!wardrobePuzzle && wardrobePuzzleFirstHelp) { checkRoom3TablePos(playerPosition, playerPositionBefore); }

// Kollision mit dem Hexagon überprüfen checkHexagonPos(playerPosition);

// Kollision mit Gegenständen überprüfen checkCollisionWithItems(playerPosition, playerPositionBefore); });

// Funktion zum Deaktivieren des Hexagons nach Ablauf der Zeit function clearHexagon(elem, hexagonActive) {
if (!hexagon1Active || !hexagon2Active || !hexagon3Active) { hexagonOffSound.play();
elem.style.backgroundImage = "url('/images/general/hexagon-gray.png')";
if (hexagonActive == 1) {
hexagon1Active = false;
} else if (hexagonActive == 2) { hexagon2Active = false;
} else {
hexagon3Active = false;
}
}
}

// Funktion zum Überprüfen der Position des Hexagons function checkHexagonPos(playerPosition) {
if (hexagonVisible) {
if (actualRoom == 0 && !hexagon1Active && playerPosition.left >= 280 && playerPosition.left <= 295 && playerPosition.top >= 515 && playerPosition.top <= 535) {
const hexagon1Elem = document.getElementById("hexagon1"); hexagon1Elem.style.backgroundImage = "url('/images/general/hexagon-blue.png')"; hexagonSound.play();
hexagon1Active = true;
setTimeout(() => clearHexagon(hexagon1Elem, 1), 15000);
}
if (actualRoom == 1 && !hexagon2Active && playerPosition.left >= 10 && playerPosition.left <= 25 && playerPosition.top >= 155 && playerPosition.top <= 180) {
const hexagon2Elem = document.getElementById("hexagon2"); hexagon2Elem.style.backgroundImage = "url('/images/general/hexagon-green.png')"; hexagonSound.play();
hexagon2Active = true;
setTimeout(() => clearHexagon(hexagon2Elem, 2), 3000); if (hexagon1Active && hexagon2Active && hexagon3Active) { hexagonPuzzle = true;
hexagonPuzzleFirstHelp = false;
puzzleSeconds = 0;

let door = document.querySelector(".door-3"); doorSound.play();

door.setAttribute("data-state", "open");

if (lightRoom3State) {
const lightRoom3 = document.getElementById("lightRoom3"); lightRoom3.style.backgroundColor = "transparent";
}
}
}
if (actualRoom == 2 && !hexagon3Active && playerPosition.left >= 10 && playerPosition.left <= 25 && playerPosition.top >= 505 && playerPosition.top <= 530) {
const hexagon3Elem = document.getElementById("hexagon3"); hexagon3Elem.style.backgroundImage = "url('/images/general/hexagon-red.png')"; hexagonSound.play();
hexagon3Active = true;
setTimeout(() => clearHexagon(hexagon3Elem, 3), 9000); }
}
}

/* ################################################################
Filename | : room1.js
Author | : Bohn Matthias
Date | : 26.05.2024
################################################################ */

// Variable zur Überprüfung, ob der Spiegel im Raum 1 sichtbar ist let mirror1Visible = false;

// ID des Intervalls für die Feuchtigkeitsüberprüfung
let intervalIdHumidity;

// Objekte im Raum 1 mit ihren Positionen und Abmessungen const room1Objects = [
{ id: "pc-table", top: 5, left: 10, width: 78, height: 25 }, { id: "mirror", top: 0, left: 160, width: 55, height: 6 }, { id: "pc-chair", top: 20, left: 35, width: 26, height: 29 }, ];

// Funktion zur Überprüfung der Position des Spiegels im Raum 1
function checkRoom1MirrorPos(playerPosition, playerPositionBefore) {
const playerElement = document.querySelector("#player");
if (actualRoom == 1 && playerPosition.left >= 156 && playerPosition.left <= 186 && playerPosition.top >= 6 && playerPosition.top <= 21) {

playerElement.classList.add("show-after"); // Füge eine Klasse hinzu, um das zusätzliche Bild anzuzeigen

// Abonniere das Thema, um die Feuchtigkeitsdaten zu erhalten subscribe_topic(HUMIDITY_TOPIC);

// Füge den Event-Listener für das Tastaturereignis "keydown" hinzu document.addEventListener("keydown", showMirror1);
} else if (actualRoom == 1 && playerPositionBefore.left >= 156 && playerPositionBefore.left <= 186 && playerPositionBefore.top >= 6 && playerPositionBefore.top <= 21 && (playerPosition.left < 156 || playerPosition.left > 186 || playerPosition.top < 6 || playerPosition.top > 21)) {
playerElement.classList.remove("show-after"); // Entferne die Klasse, um das zusätzliche Bild auszublenden

// Entferne den Event-Listener
document.removeEventListener("keydown", showMirror1); document.querySelector("#mirror").style.display = "none"; document.querySelector("#mirror").classList.remove("animateMirror"); // Entferne die Animationsklasse
document.querySelector("#mirror p").classList.remove("animate-mirror-p"); // Entferne die Animationsklasse für den Text document.querySelector("#player-background").classList.remove("animate-layer-background"); // Entferne die Animationsklasse für den Hintergrund

// Abonnement vom Thema HUMIDITY_TOPIC kündigen client.unsubscribe(HUMIDITY_TOPIC, {
onSuccess: function () {
console.log("Abonnement von " + HUMIDITY_TOPIC + " gekündigt"); }
});

// Sende Nachricht mit Wert 0, um die Feuchtigkeitsübertragung zu stoppen message = new Paho.MQTT.Message("0");
message.destinationName = HUMIDITY_SEND_TOPIC;
message.retained = true;
console.log("< PUB", message.destinationName, "0"); client.send(message);

clearInterval(intervalIdHumidity);

mirror1Visible = false; // Aktualisiere den Zustand auf unsichtbar }
}

// Funktion zur Anzeige des Spiegels im Raum 1
function showMirror1(event) {
// Überprüfe, ob die gedrückte Taste die "Space"-Taste ist if (event.code === "Space") {

// Wenn der Spiegel sichtbar ist, setze das Display auf "none"
if (mirror1Visible) {
document.querySelector("#mirror").style.display = "none"; document.querySelector("#mirror").classList.remove("animateMirror"); // Entferne die Animationsklasse
document.querySelector("#mirror p").classList.remove("animate-mirror-p"); // Entferne die Animationsklasse für den Text document.querySelector("#player-background").classList.remove("animate-layer-background"); // Entferne die Animationsklasse für den Hintergrund

// Abonnement vom Thema HUMIDITY_TOPIC kündigen client.unsubscribe(HUMIDITY_TOPIC, {
onSuccess: function () {
console.log("Abonnement von " + HUMIDITY_TOPIC + " gekündigt"); }
});

// Sende Nachricht mit Wert 0, um die Feuchtigkeitsübertragung zu stoppen
message = new Paho.MQTT.Message("0");
message.destinationName = HUMIDITY_SEND_TOPIC;
message.retained = true;
console.log("< PUB", message.destinationName, "0"); client.send(message);

clearInterval(intervalIdHumidity);

mirror1Visible = false; // Aktualisiere den Zustand auf unsichtbar
} else {
// Andernfalls setze das Display auf "block", füge die Animationsklassen hinzu und aktualisiere den Zustand auf sichtbar
const pwDoor2Elem = document.getElementById("pw-door-2"); pwDoor2Elem.innerText = passwordDoor2[randompasswordDoor2Number - 1];

document.querySelector("#mirror").style.display = "block";

firstHumidityPub = true;

// Sende Nachricht mit Wert 1, um die Feuchtigkeitsübertragung zu starten
message = new Paho.MQTT.Message("1");
message.destinationName = HUMIDITY_SEND_TOPIC;
message.retained = true;
console.log("< PUB", message.destinationName, "1"); client.send(message);

// Überprüfe die Feuchtigkeit und führe die Animation aus checkHumidityAndAnimate();

mirror1Visible = true;

}
}
}

// Funktion zur Überprüfung der Feuchtigkeitsdaten und Ausführung der Animation
function checkHumidityAndAnimate() {
// Setze ein Intervall, das alle 200ms überprüft intervalIdHumidity = setInterval(() => {
if (humidity > firstHumidity + 15) {
// Stoppe das Intervall, wenn die Bedingung erfüllt ist clearInterval(intervalIdHumidity);

// Führe die Animationsbefehle aus document.querySelector("#mirror").classList.add("animateMirror"); document.querySelector("#mirror p").classList.add("animate-mirror-p"); document.querySelector("#player-background").classList.add("animate-layer-background");
}
}, 200);
}

// Funktion zur Überprüfung der Position des PCs im Raum 1 function checkRoom1PcPos(playerPosition, playerPositionBefore) { if (playerPosition.left >= 0 && playerPosition.left <= 88 && playerPosition.top >= 30 && playerPosition.top <= 60) {

// Füge den Event-Listener für das Tastaturereignis "keydown" hinzu if (!mirrorPuzzle) {
document.addEventListener("keydown", showMirrorPuzzleInfo);
} else if (mirrorPuzzle && morseCodePuzzle && !lightSwitch3Puzzle) { document.addEventListener("keydown", showLightSwitch3PuzzleInfo); }
} else if (actualRoom == 1 && playerPositionBefore.left >= 0 && playerPositionBefore.left <= 88 && playerPositionBefore.top >= 30 && playerPositionBefore.top <= 60 && (playerPosition.left < 0 || playerPosition.left > 88 || playerPosition.top < 30 || playerPosition.top > 60)) {
// Ursprüngliche Stile wiederherstellen, wenn das Jumbotron ausgeblendet wird
jumbotronElem.style.display = "none";
jumbotronElem.style.background = "steelblue"; jumbotronElem.style.borderRadius = "8px"; jumbotronElem.style.boxShadow = "snow 0px 0px 26px 5px"; jumbotronElem.style.alignItems = "center"; jumbotronElem.style.border = "none";

jumbotronVisible = false;

// Entferne den Event-Listener für das Tastaturereignis "keydown"

if (!mirrorPuzzle) {
document.removeEventListener("keydown", showMirrorPuzzleInfo);
} else if (mirrorPuzzle && morseCodePuzzle && !lightSwitch3Puzzle) { document.removeEventListener("keydown", showLightSwitch3PuzzleInfo); }
}
}

// Funktion zur Anzeige der Spiegelrätsel-Informationen function showMirrorPuzzleInfo(event) {
if (event.code === "Space") {
let jumbotronElem = document.querySelector(".jumbotron");

if (jumbotronVisible) {
// Ursprüngliche Stile wiederherstellen, wenn das Jumbotron ausgeblendet wird
jumbotronElem.style.display = "none";
jumbotronElem.style.background = "steelblue"; jumbotronElem.style.borderRadius = "8px"; jumbotronElem.style.boxShadow = "snow 0px 0px 26px 5px"; jumbotronElem.style.alignItems = "center"; jumbotronElem.style.border = "none";

jumbotronVisible = false;
} else {
// Zeige die Informationen zum Spiegelrätsel an const today = new Date().toLocaleDateString(); const mail = `
<p><b>NEUE E-MAIL</b></p>
<p><b>Von:</b> ESCAPE ROOM SYSTEM</p> <p><b>An:</b> SPIELER</p>
<p><b>Datum:</b> ${today}</p>
<br>
<p><b>Nachricht:</b></p>
<p>Was unsichtbar ist, wird sichtbar, wenn der Atem der Natur es berührt.</p>
`;
jumbotronElem.innerHTML = mail;

jumbotronElem.style.display = "flex"; jumbotronElem.style.background = "#e6e5e5"; jumbotronElem.style.borderRadius = "0"; jumbotronElem.style.border = "2px solid"; jumbotronElem.style.boxShadow = "snow 0px 0px 8px 0px"; jumbotronElem.style.alignItems = "flex-start";

jumbotronVisible = true;
}
}
}

// Funktion zur Anzeige der Lichtschalter 3 Rätsel-Informationen function showLightSwitch3PuzzleInfo(event) {
if (event.code === "Space") {
let jumbotronElem = document.querySelector(".jumbotron");

if (jumbotronVisible) {
// Ursprüngliche Stile wiederherstellen, wenn das Jumbotron ausgeblendet wird
jumbotronElem.style.display = "none";
jumbotronElem.style.background = "steelblue"; jumbotronElem.style.borderRadius = "8px"; jumbotronElem.style.boxShadow = "snow 0px 0px 26px 5px"; jumbotronElem.style.alignItems = "center"; jumbotronElem.style.border = "none";

jumbotronVisible = false;
} else {
// Zeige die Informationen zum Lichtschalter 3 Rätsel an const today = new Date().toLocaleDateString();
const mail = `
<p><b>NEUE E-MAIL</b></p>
<p><b>Von:</b> ESCAPE ROOM SYSTEM</p> <p><b>An:</b> SPIELER</p>
<p><b>Datum:</b> ${today}</p>
<br>
<p><b>Nachricht:</b></p>
<p>Finde den dritten von drei, um den Pfad zu erleuchten.</p> `;
jumbotronElem.innerHTML = mail;

jumbotronElem.style.display = "flex"; jumbotronElem.style.background = "#e6e5e5"; jumbotronElem.style.borderRadius = "0"; jumbotronElem.style.border = "2px solid"; jumbotronElem.style.boxShadow = "snow 0px 0px 8px 0px"; jumbotronElem.style.alignItems = "flex-start";

jumbotronVisible = true;
}
}
}

// Funktion zur Überprüfung der Bewegung an der rechten Wand im Raum 1 function checkMoveRoom1RightWall(playerPositionBefore, playerPosition) { if (playerPositionBefore.left >= 244 && playerPosition.left < 244 && playerPosition.top < 244) {
if (!(playerPosition.top >= 85 && playerPosition.top <= 115 && canMoveThroughDoor(1))) {
playerPosition.left = 244;

actualRoom = 0; // Setze den Spieler zurück in Raum 0 } else {
playerPosition.left = 201;
actualRoom = 1; // Setze den Spieler zurück in Raum 1
}
} else {
if (playerPositionBefore.left <= 201 && playerPosition.left > 201 && playerPosition.top < 244) {
if (!(playerPosition.top >= 85 && playerPosition.top <= 115 && canMoveThroughDoor(1))) {
playerPosition.left = 201;
actualRoom = 1; // Setze den Spieler zurück in Raum 1
} else {
playerPosition.left = 244;
actualRoom = 0; // Setze den Spieler zurück in Raum 0 }
}
}
}

// Funktion zur Überprüfung der Bewegung an der unteren Wand im Raum 1 function checkMoveRoom1BottomWall(playerPositionBefore, playerPosition) { if (playerPosition.left < 244 && playerPositionBefore.top <= 202 && playerPosition.top > 202) {
playerPosition.top = 202; // Setze den Spieler zurück an die obere Grenze der unteren Wand
}
if (playerPosition.left < 244 && playerPositionBefore.top >= 244 && playerPosition.top < 244) {
playerPosition.top = 244; // Setze den Spieler zurück an die untere Grenze der unteren Wand
}
}

/* ################################################################
Filename | : room2.js
Author | : Bohn Matthias
Date | : 26.05.2024
################################################################ */

// Liste der Objekte im Raum 2
const room2Objects = [
{ id: "morse-code-device", top: 405, left: 205, width: 26, height: 47 }, { id: "pc-table2", top: 554, left: 105, width: 78, height: 30 },
];
// Passwort für Tür 2
const passwordDoor2 = ["trowssap", "esp8266", "wasd1234"];

// Zufällige Auswahl eines Passworts
const randompasswordDoor2Number = Math.floor(Math.random() * 3) + 1;

// Mögliche Morsecode-Nachrichten
const morseCodeMessage = ["sos", "sek", "nsa"];

// Zufällige Auswahl einer Morsecode-Nachricht
const randomMorseCodeNumber = Math.floor(Math.random() * 3) + 1;

// Morsecode-Sound
const morseCodeSound = new Audio('../sounds/morsesound.mp3'); morseCodeSound.volume = 0.2;

// Funktion zur Überprüfung der Bewegung an der oberen Wand des Raums 2 function checkMoveRoom2TopWall(playerPositionBefore, playerPosition) { // Raum 2 Obere Wand
if (
playerPosition.left < 244 &&
playerPositionBefore.top <= 306 && playerPosition.top > 306
) {
if (
!(
playerPosition.left >= 85 && playerPosition.left <= 115 && canMoveThroughDoor(2)
)
) {
playerPosition.top = 306;
actualRoom = 0;
} else {
playerPosition.top = 348;
actualRoom = 2;
}
}

if (
playerPosition.left < 244 && playerPositionBefore.top >= 348 && playerPosition.top < 348
) {
if (
!(
playerPosition.left >= 85 && playerPosition.left <= 115 && canMoveThroughDoor(2)
)
) {
playerPosition.top = 348;
actualRoom = 2;

} else {
playerPosition.top = 306;
actualRoom = 0;
}
}
}

// Funktion zur Überprüfung der Bewegung an der rechten Wand des Raums 2 function checkMoveRoom2RightWall(playerPositionBefore, playerPosition) { // Raum 2 Rechte Wand
if (
playerPositionBefore.left >= 244 &&
playerPosition.left < 244 && playerPosition.top > 306
) {
playerPosition.left = 244;
}
if (
playerPositionBefore.left <= 201 && playerPosition.left > 201 && playerPosition.top > 306
) {
playerPosition.left = 201; }
}

// Funktion zur Überprüfung der Position der Tür im Raum 2 function checkRoom2DoorPos(playerPosition, playerPositionBefore) { const playerElement = document.getElementById("player");
if (playerPosition.left >= 70 && playerPosition.left <= 130 && playerPosition.top >= 290 && playerPosition.top <= 306 && !canMoveThroughDoor(2)) {
playerElement.classList.add("show-after"); // Füge eine Klasse hinzu, um das zusätzliche Bild anzuzeigen

// Füge den Event-Listener für das Tastaturereignis "keydown" hinzu document.addEventListener("keydown", showDoor2PwDialog);
} else if (playerPositionBefore.left >= 70 && playerPositionBefore.left <= 130 && playerPositionBefore.top >= 290 && playerPositionBefore.top <= 306 && (playerPosition.left < 70 || playerPosition.left > 130 || playerPosition.top < 290 || playerPosition.top > 306)) { playerElement.classList.remove("show-after"); // Entferne die Klasse, um das zusätzliche Bild auszublenden

// Entferne den Event-Listener
document.removeEventListener("keydown", showDoor2PwDialog); document.querySelector(".jumbotron").style.display = "none"; jumbotronVisible = false; // Aktualisiere den Zustand auf unsichtbar }
}

// Funktion zur Anzeige des Passwortdialogs für Tür 2 function showDoor2PwDialog(event) {
if (event.code === "Space") {
let jumbotronElem = document.querySelector(".jumbotron");

if (jumbotronVisible) {
jumbotronElem.style.display = "none"; jumbotronVisible = false;
} else {
jumbotronElem.innerHTML = `
<h2>Passwort</h2>
<input type="password" name="door2pw" id="door2pw" />
`;

// Ensuring the focus is set after the element is rendered and visible setTimeout(() => {
const inputElem = document.getElementById("door2pw");
// Set focus to the input field
inputElem.focus();

inputElem.addEventListener("change", (e) => {
let inputValue = e.target.value.toLowerCase();

if (inputValue == passwordDoor2[randompasswordDoor2Number - 1]) {

mirrorPuzzle = true;
mirrorPuzzleFirstHelp = false;
puzzleSeconds = 0;

// Zugreifen auf das Tür-Element
const door = document.querySelector(".door-2");
// Zugrifff auf die Raumhelligkeit
const lightRoom2 = document.getElementById("lightRoom2"); // Ändern des data-state-Attributs auf "open" doorSound.play();
door.setAttribute("data-state", "open");

lightRoom2.style.backgroundColor = "#00000000"; }
});
}, 0);

jumbotronElem.style.display = "flex"; jumbotronVisible = true;
}
}
}

// Variable zur Überprüfung, ob der Morsecode bereits gesendet wurde

let messageSent = false;

// Funktion zur Überprüfung der Position des Morsecode-Geräts im Raum 2 function checkRoom2MorseCodePos(playerPosition, playerPositionBefore) { const playerElement = document.querySelector("#player");
if (actualRoom == 2 && playerPosition.left > 160 && playerPosition.left <= 170 && playerPosition.top > 395 && playerPosition.top < 428) { playerElement.classList.add("show-after"); // Füge eine Klasse hinzu, um das zusätzliche Bild anzuzeigen

// Überprüfe, ob die Nachricht noch nicht gesendet wurde
if (!messageSent) {
// Senden der Nachricht
message = new Paho.MQTT.Message("" + randomMorseCodeNumber); message.destinationName = MORSECODE_NR_TOPIC; message.retained = true;
console.log("< PUB", message.destinationName, "" + randomMorseCodeNumber);
client.send(message);

// Markiere, dass die Nachricht gesendet wurde messageSent = true;
}

// Füge den Event-Listener für das Tastaturereignis "keydown" hinzu document.addEventListener("keydown", showRoom2MorseCodeDialog);
} else if (actualRoom == 2 && playerPositionBefore.left >= 160 && playerPositionBefore.left <= 170 && playerPositionBefore.top >= 395 && playerPositionBefore.top <= 428 && (playerPosition.left < 160 || playerPosition.left > 170 || playerPosition.top < 395 || playerPosition.top > 428)) {
playerElement.classList.remove("show-after"); // Entferne die Klasse, um das zusätzliche Bild auszublenden

// Sende Nachricht mit Wert 0
message = new Paho.MQTT.Message("0"); message.destinationName = MORSECODE_NR_TOPIC; message.retained = true;
console.log("< PUB", message.destinationName, "0"); client.send(message);

// Setze messageSent zurück auf false
messageSent = false;

// Entferne den Event-Listener document.querySelector(".jumbotron").style.display = "none"; document.removeEventListener("keydown", showRoom2MorseCodeDialog); }
}

// Funktion zur Anzeige des Dialogs für den Morsecode im Raum 2 function showRoom2MorseCodeDialog(event) {
if (event.code === "Space") {
let jumbotronElem = document.querySelector(".jumbotron");

if (jumbotronVisible) {
jumbotronElem.style.display = "none"; jumbotronVisible = false;
} else {
jumbotronElem.innerHTML = `
<h2>Nachricht?</h2>
<input type="text" name="morseCodeMessage" id="morseCodeMessage" /> `;

jumbotronElem.style.display = "flex";
jumbotronVisible = true;

// Ensuring the focus is set after the element is rendered and visible setTimeout(() => {
const inputElem = document.getElementById("morseCodeMessage"); inputElem.focus();

inputElem.addEventListener("change", (e) => {
let inputValue = e.target.value.toLowerCase();
if (inputValue == morseCodeMessage[randomMorseCodeNumber - 1]) {

morseCodePuzzle = true;
morseCodePuzzleFirstHelp = false;
puzzleSeconds = 0;

hexagonOffSound.play();
document.getElementById("hexagon1").style.display = "block"; document.getElementById("hexagon2").style.display = "block"; document.getElementById("hexagon3").style.display = "block"; hexagonVisible = true;
}
});
}, 0);
}
}
}

function checkRoom2TablePos(playerPosition, playerPositionBefore) {
if (actualRoom == 2 && playerPosition.left >= 130 && playerPosition.left <= 160 && playerPosition.top >= 504 && playerPosition.top <= 519) {

// Füge den Event-Listener für das Tastaturereignis "keydown" hinzu document.addEventListener("keydown", showMorseCodePuzzleInfo);

} else if (actualRoom == 2 && playerPositionBefore.left >= 130 && playerPositionBefore.left <= 160 && playerPositionBefore.top >= 504 && playerPositionBefore.top <= 519 && (playerPosition.left < 130 || playerPosition.left > 160 || playerPosition.top < 504 || playerPosition.top > 519)) {
// Ursprüngliche Stile wiederherstellen, wenn das Jumbotron ausgeblendet wird
jumbotronElem.style.display = "none";
jumbotronElem.style.background = "steelblue"; jumbotronElem.style.borderRadius = "8px"; jumbotronElem.style.boxShadow = "snow 0px 0px 26px 5px"; jumbotronElem.style.alignItems = "center"; jumbotronElem.style.border = "none";

jumbotronVisible = false;

// Entferne den Event-Listener für das Tastaturereignis "keydown" hinzu document.removeEventListener("keydown", showMorseCodePuzzleInfo);

}
}
function showMorseCodePuzzleInfo(event) {
if (event.code === "Space") {
let jumbotronElem = document.querySelector(".jumbotron");

if (jumbotronVisible) {
// Ursprüngliche Stile wiederherstellen, wenn das Jumbotron ausgeblendet wird
jumbotronElem.style.display = "none";
jumbotronElem.style.background = "steelblue"; jumbotronElem.style.borderRadius = "8px"; jumbotronElem.style.boxShadow = "snow 0px 0px 26px 5px"; jumbotronElem.style.alignItems = "center"; jumbotronElem.style.border = "none";

jumbotronVisible = false;
} else {
const today = new Date().toLocaleDateString(); const faxMessage = `
<p><b>FAX-NACHRICHT</b></p>
<p><b>Von:</b> ESCAPE ROOM SYSTEM</p> <p><b>An:</b> SPIELER</p>
<p><b>Datum:</b> ${today}</p>
<br>
<p><b>Nachricht:</b></p>
<p>Blinkende Lichter tanzen im Rhythmus der Punkte und Striche.</p> <p>Die Antwort liegt in den alten Mustern.</p>
<p>Erkenne 3 Zeichen, um den Weg zu finden.</p>
`;
jumbotronElem.innerHTML = faxMessage;

jumbotronElem.style.display = "flex"; jumbotronElem.style.background = "#e6e5e5"; jumbotronElem.style.borderRadius = "0"; jumbotronElem.style.border = "2px solid"; jumbotronElem.style.boxShadow = "snow 0px 0px 8px 0px"; jumbotronElem.style.alignItems = "flex-start";

jumbotronVisible = true;
}
}
}

/* ################################################################
Filename | : room3.js
Author | : Bohn Matthias
Date | : 26.05.2024
################################################################ */

// Liste der Objekte im Raum 3
const room3Objects = [
{ id: "table-dining", top: 380, left: 440, width: 86, height: 150 }, { id: "schrank", top: 0, left: 435, width: 99, height: 28 },
{ id: "reader", top: 160, left: 348, width: 30, height: 34 },
];

let rfidCount = 0;
let lightRoom3State = false;

// Funktion zur Überprüfung der Bewegung an der linken Wand des Raums 3 function checkMoveRoom3LeftWall(playerPositionBefore, playerPosition) { // Überprüfung der linken Wand im Raum 3
if (playerPositionBefore.left <= 305 && playerPosition.left > 305) { if (!(playerPosition.top >= 260 && playerPosition.top <= 290 && canMoveThroughDoor(3))) {
playerPosition.left = 305;
actualRoom = 0;
} else {
playerPosition.left = 348; actualRoom = 3;
}
}

// Überprüfung der linken Wand im Raum 3 (umgekehrte Richtung)
if (playerPositionBefore.left >= 348 && playerPosition.left < 348) { if (!(playerPosition.top >= 260 && playerPosition.top <= 290 && canMoveThroughDoor(3))) {
playerPosition.left = 348;

actualRoom = 3;
} else {
playerPosition.left = 305; actualRoom = 0;
}
}
}

// Funktion zur Überprüfung der Position des Lichtschalters im Raum 3 function checkRoom3LightSwitchPos(playerPosition, playerPositionBefore) { const playerElement = document.querySelector("#player");
// Überprüfung, ob der Spieler sich in der Nähe des Lichtschalters befindet und ob er sich im Raum 3 befindet
if (playerPosition.left > 300 && playerPosition.left <= 305 && playerPosition.top >= 320 && playerPosition.top <= 340 && actualRoom == 0) { playerElement.classList.add("show-after"); // Klasse hinzufügen, um zusätzliches Bild anzuzeigen

// Event-Listener für das Tastaturereignis "keydown" hinzufügen, um die Taste zu lesen
readButton(true);
} else if (actualRoom == 0 && playerPositionBefore.left > 300 && playerPositionBefore.left <= 305 && playerPositionBefore.top >= 320 && playerPositionBefore.top <= 340 && (playerPosition.left < 300 || playerPosition.left > 305 || playerPosition.top < 320 || playerPosition.top > 340)) {
playerElement.classList.remove("show-after"); // Klasse entfernen, um zusätzliches Bild auszublenden

readButton(false);
}
}

// Funktion zur Überprüfung der Position des Schranks im Raum 3
function checkRoom3WardrobePos(playerPosition, playerPositionBefore) { const playerElement = document.querySelector("#player");
// Überprüfung, ob der Spieler sich in der Nähe des Schranks befindet und ob er sich im Raum 3 befindet
if (playerPosition.left > 440 && playerPosition.left < 495 && playerPosition.top >= 20 && playerPosition.top < 40 && actualRoom == 3) { playerElement.classList.add("show-after"); // Klasse hinzufügen, um zusätzliches Bild anzuzeigen

// Sende Nachricht mit Wert 0
message = new Paho.MQTT.Message("1"); message.destinationName = TOPIC_SEND_LDR; message.retained = true;
console.log("< PUB", message.destinationName, "1"); client.send(message);

// Füge den Event-Listener für das Tastaturereignis "keydown" hinzu document.addEventListener("keydown", showWardrobe);
} else if (actualRoom == 3 && playerPositionBefore.left > 440 && playerPositionBefore.left < 495 && playerPositionBefore.top >= 20 && playerPositionBefore.top < 40 && (playerPosition.left < 440 || playerPosition.left > 495 || playerPosition.top < 20 || playerPosition.top > 40)) {
playerElement.classList.remove("show-after"); // Klasse entfernen, um zusätzliches Bild auszublenden

// Entferne den Event-Listener document.removeEventListener("keydown", showWardrobe);

// Sende Nachricht mit Wert 1
message = new Paho.MQTT.Message("0"); message.destinationName = TOPIC_SEND_LDR; message.retained = true;
console.log("< PUB", message.destinationName, "0"); client.send(message);

const wardrobeElem = document.getElementById("wardrobe-open"); wardrobeElem.style.display = "none";

readLdr(false);
}
}

// Funktion zum Lesen der Taste
function readButton(event) {
if (event) {
subscribe_topic(BUTTON3_TOPIC); // Funktion zum Abonnieren des Themas aufrufen
} else {
// Abonnement vom Thema BUTTON3_TOPIC kündigen client.unsubscribe(BUTTON3_TOPIC, {
onSuccess: function () {
console.log("Abonnement von " + BUTTON3_TOPIC + " gekündigt"); }
});
}
}

// Funktion zum Umschalten des Lichts im Raum 3
function toggleLightRoom3() {
const lightRoom3 = document.getElementById("lightRoom3");
const lightSwitchRoom3 = document.getElementById("lightSwitch");

// Berechnet den aktuellen Hintergrundstil des Lichtschalters const computedStyle = window.getComputedStyle(lightSwitchRoom3); const backgroundColor = computedStyle.backgroundColor;

if (!lightRoom3State) {
// Wenn der Lichtschalter aus ist, ändere ihn zu gelb und schalte das Licht ein
lightRoom3State = true;
lightSwitchRoom3.style.backgroundColor = "#fdf300";
if (canMoveThroughDoor(3)) { lightRoom3.style.backgroundColor = "transparent"; lightSwitch3Puzzle = true; lightSwitch3PuzzleFirstHelp = false;
}
} else {
// Wenn der Lichtschalter an ist, ändere ihn zu weiß und schalte das Licht aus
lightRoom3State = false;
lightSwitchRoom3.style.backgroundColor = "#ffffff"; lightRoom3.style.backgroundColor = "#000000f3";
}
}

// Funktion zum Anzeigen des Schranks
function showWardrobe(event) {
// Überprüft, ob die gedrückte Taste die Leertaste ist
if (event.code === "Space") {
const wardrobeElem = document.getElementById("wardrobe-open"); wardrobeElem.style.display = "block"; // Schrank anzeigen readLdr(true); // Beginnt, den LDR-Sensor zu lesen
}
}

// Funktion zum Lesen der Helligkeit
function readLdr(event) {
if (event) {
subscribe_topic(LDR_TOPIC); // Funktion zum Abonnieren des Themas aufrufen
} else {
// Abonnement vom Thema LDR_TOPIC kündigen client.unsubscribe(LDR_TOPIC, {
onSuccess: function () {
console.log("Abonnement von " + LDR_TOPIC + " gekündigt"); }
});
}
}

// Funktion zur Anzeige des RFID-Chips
function showRfidChip(state) {
const rfidElem = document.getElementById("rfid-chip");
const wardrobeLightElem = document.getElementById("wardrobe-light");

if (state) {
// Licht des Schranks ausblenden wardrobeLightElem.style.opacity = "0";

// Puzzle-Status aktualisieren wardrobePuzzle = true;
wardrobePuzzleFirstHelp = false; puzzleSeconds = 0;

if (rfidElem) {
// RFID-Chip sichtbar machen
rfidElem.style.opacity = "1";

// Event-Listener hinzufügen, um den RFID-Chip beim Klicken zu entfernen
rfidElem.addEventListener("click", (e) => {
rfidElem.remove();
document.getElementById("rfid-chip-bag").style.display = "block"; });
}

} else {
// Licht des Schranks wieder einblenden wardrobeLightElem.style.opacity = "1";

if (rfidElem) {
// RFID-Chip unsichtbar machen rfidElem.style.opacity = "0"; }
}
}

// Funktion zur Überprüfung der Position des rfid Lesegeräts im Raum 3 function checkRoom3ReaderPos(playerPosition, playerPositionBefore) { const playerElement = document.querySelector("#player");
// Überprüfung, ob der Spieler sich in der Nähe des rfid
Lesegeräts befindet und ob er sich im Raum 3 befindet
if (playerPosition.left >= 377 && playerPosition.left < 385 && playerPosition.top >= 140 && playerPosition.top <= 170 && actualRoom == 3) { playerElement.classList.add("show-after"); // Klasse hinzufügen, um zusätzliches Bild anzuzeigen

if (document.getElementById("rfid-chip-bag").style.display != "") { // Sende Nachricht mit Wert 0
message = new Paho.MQTT.Message("2");
message.destinationName = RFID_SEND_TOPIC;
message.retained = true;
console.log("< PUB", message.destinationName, "2");

client.send(message);

subscribe_topic(RFID_UID_TOPIC);
}

// Füge den Event-Listener für das Tastaturereignis "keydown" hinzu document.addEventListener("keydown", checkRfid);
} else if (actualRoom == 3 && playerPositionBefore.left >= 377 && playerPositionBefore.left < 385 && playerPositionBefore.top >= 140 && playerPositionBefore.top <= 170 && (playerPosition.left < 377 || playerPosition.left > 385 || playerPosition.top < 140 || playerPosition.top > 170)) {
playerElement.classList.remove("show-after"); // Klasse entfernen, um zusätzliches Bild auszublenden

// Sende Nachricht mit Wert 0
message = new Paho.MQTT.Message("0"); message.destinationName = RFID_SEND_TOPIC; message.retained = true;
console.log("< PUB", message.destinationName, "0"); client.send(message);

// Entferne den Event-Listener document.removeEventListener("keydown", checkRfid); document.querySelector(".jumbotron").style.display = "none"; jumbotronVisible = false; // Aktualisiere den Zustand auf unsichtbar }
}

function checkRfid(event) {
if (event.code === "Space") {
let jumbotronElem = document.querySelector(".jumbotron");

if (jumbotronVisible) {
jumbotronElem.style.display = "none"; jumbotronVisible = false;
} else {

if (win && mirrorPuzzle && morseCodePuzzle && hexagonPuzzle && lightSwitch3Puzzle && wardrobePuzzle) {

doorSound.play();
clearInterval(updateTimeInterval);

// Zugreifen auf das Tür-Element
const door = document.querySelector(".door-master"); door.setAttribute("data-state", "open");

const minutes = Math.floor(seconds / 60);
const secs = seconds % 60;

// Formatiere die Zeit
const formattedTime = `${pad(minutes)}:${pad(secs)}`;

jumbotronElem.innerHTML = `
<h2>👌 Mission Erfolgreich</h2>
<h3>Du hast alle Rätsel erfolgreich gelöst</h3> <h3>Deine Zeit: ${formattedTime}</h3>
`;

jumbotronElem.style.display = "flex"; jumbotronVisible = true;

} else if (rfidCount >= 3) { jumbotronElem.innerHTML = `
<h2>!Mission gescheitert!</h2>
<h3>Das Haus bleibt nun für immer verschlossen!</h3> `;

jumbotronElem.style.display = "flex";
jumbotronVisible = true;
} else {

jumbotronElem.innerHTML = `
<h2>!Warnung!</h2>
<h3>Du hast noch ${3 - rfidCount} Versuche</h3> `;

rfidCount++;

jumbotronElem.style.display = "flex"; jumbotronVisible = true;
}
}
}
}

function checkRoom3TablePos(playerPosition, playerPositionBefore) {
if (actualRoom == 3 && playerPosition.left >= 435 && playerPosition.left <= 500 && playerPosition.top >= 330 && playerPosition.top <= 345) {

// Füge den Event-Listener für das Tastaturereignis "keydown" hinzu document.addEventListener("keydown", showWardrobePuzzleInfo);

} else if (actualRoom == 3 && playerPositionBefore.left >= 435 && playerPositionBefore.left <= 500 && playerPositionBefore.top >= 330 && playerPositionBefore.top <= 345 && (playerPosition.left < 435 || playerPosition.left > 500 || playerPosition.top < 330 || playerPosition.top > 345)) {

// Ursprüngliche Stile wiederherstellen, wenn das Jumbotron ausgeblendet wird
jumbotronElem.style.display = "none";

jumbotronVisible = false;

// Entferne den Event-Listener für das Tastaturereignis "keydown" hinzu document.removeEventListener("keydown", showWardrobePuzzleInfo);

}
}
function showWardrobePuzzleInfo(event) {
if (event.code === "Space") {
let jumbotronElem = document.querySelector(".jumbotron");

if (jumbotronVisible) {
// Ursprüngliche Stile wiederherstellen, wenn das Jumbotron ausgeblendet wird
jumbotronElem.style.display = "none";

jumbotronVisible = false;
} else {
const today = new Date().toLocaleDateString();
const Message = `
<p><b>Hinweis:</b></p>
<p>In der Dunkelheit liegt ein Geheimnis, erleuchte es, um es zu sehen.</p>
`;
jumbotronElem.innerHTML = Message;

jumbotronElem.style.display = "flex";

jumbotronVisible = true;
}
}
}

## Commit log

2024-06-04 led red -> yellow
2024-07-01 loose sound + esp video + wardrobe d-none
    [escapeRoomSketch.ino, params.h]
